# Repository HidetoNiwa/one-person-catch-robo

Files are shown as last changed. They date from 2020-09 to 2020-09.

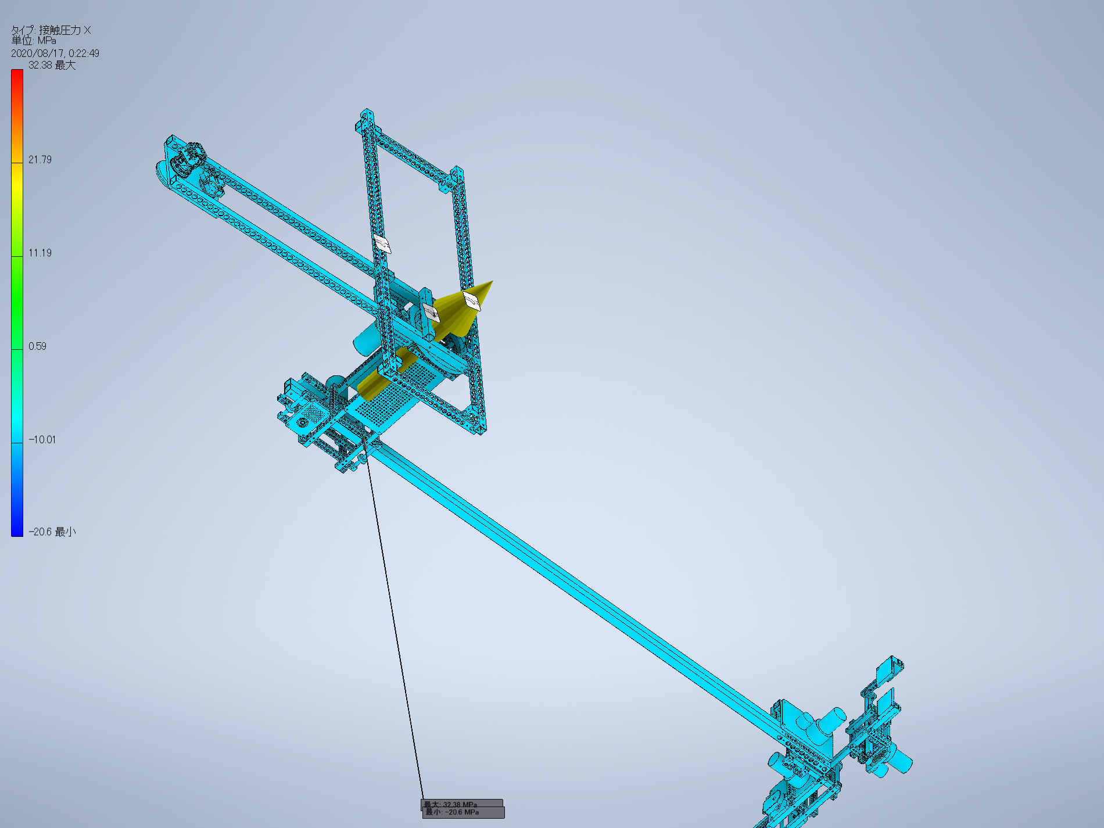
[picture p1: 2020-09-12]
CAD/ロボット/Images/ロボット.iam 構造解析レポート 2020_07_17/0/Result_0_77_rev.png

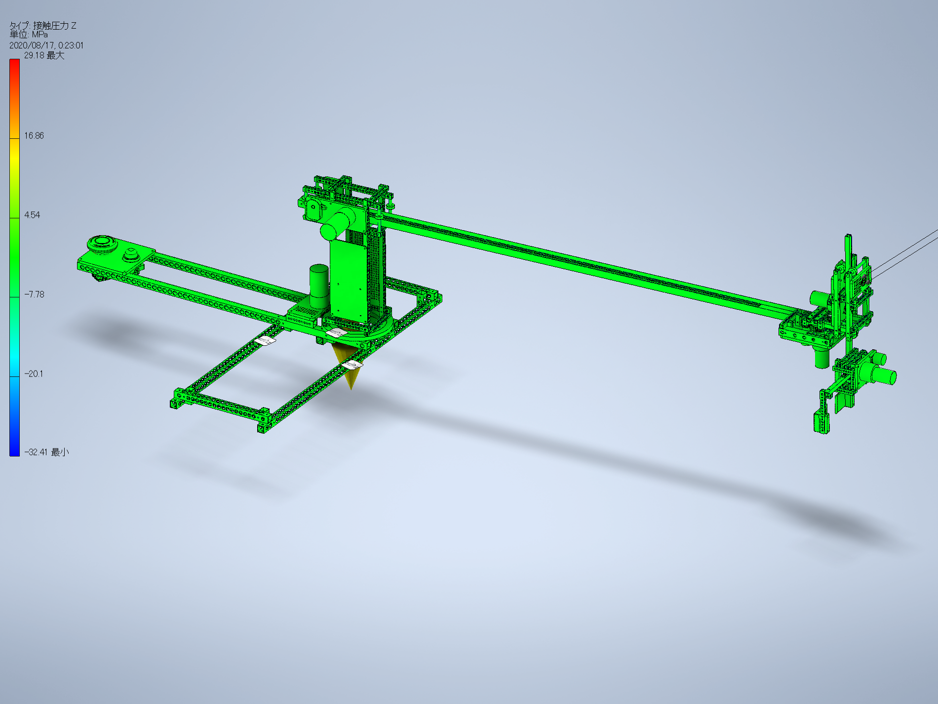
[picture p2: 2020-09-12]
CAD/ロボット/Images/ロボット.iam 構造解析レポート 2020_07_17/0/Result_0_79.png

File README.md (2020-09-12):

# one-person-catch-robo

[#１人キャチロボ]() のリポジトリ

## CAD

* 全体.iam：ロボット全体設計（フィールド込み）
* ロボット.iam：ロボット設計

そのほか、構造解析レポートとかもあります。

### 開発ソフトウェア

Autodesk Inventor Professional 2020

学生版ライセンスで使用可能

## KiCAD

* メインボード.pro：メインボードの設計

### 開発ソフトウェア

KiCAD 5.1.3

## 公式提出資料

## YOLO環境構築

### 環境

Jetson Nano

### 方法

https://www.nakasha.co.jp/future/ai/vol2_yolov3nvidia_jetson_nano.html

OpenCVのver.4系だとうまくコンパイル-できなかった

https://pickerlab.net/2018/08/06/darknet-eroor-nvcc/

### 学習用ファイルラベリング「labelimg」

参考；https://symfoware.blog.fc2.com/blog-entry-2420.html

PyQTのバージョン：5.14.1
デフォルトのインストール設定では、5.10.1になっているのを書き換える（pip配布の問題）

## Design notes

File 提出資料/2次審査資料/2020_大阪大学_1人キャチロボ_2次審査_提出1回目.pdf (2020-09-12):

# 1人キャチロボ ～阪大の老害～

大阪大学大学院 基礎工学研究科
機能創成専攻 博士前期課程1年
丹羽 英人

## 自己紹介/チーム名紹介

キャチロボバトルコンテスト参加歴
2016：Team豊中 － 選手（回路製作）
2017：阪大の老害－選手（回路製作）
2018：運営
2019：運営（学生MC）
2020：阪大の老害 ～1人キャチロボ～ － 選手（全体設計）

2年ぶり3回目の選手としての参加
（キャチロボ10年のうち5年も関わってたんだね）

## 本日の構成

1. 戦略
2. 機構紹介
3. 回路設計
4. 大会までの2週間何をするか

## コンセプト/戦略

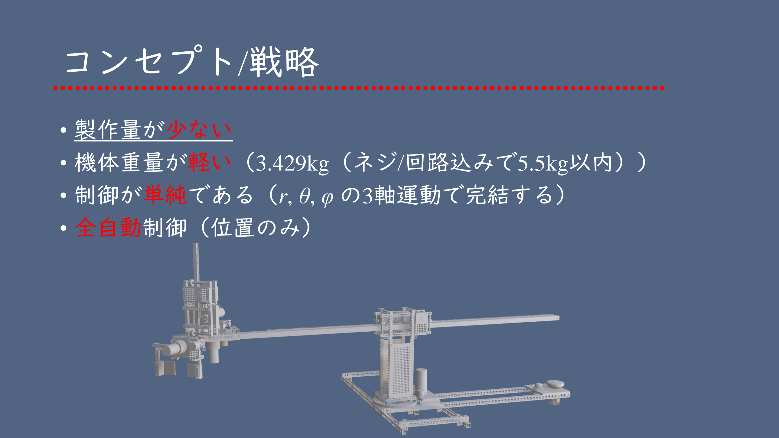
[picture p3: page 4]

- 製作量が少ない
- 機体重量が軽い（3.429kg（ネジ/回路込みで5.5kg以内））
- 制御が単純である（r, θ, φ の3軸運動で完結する）
- 全自動制御（位置のみ）

## 機体全景

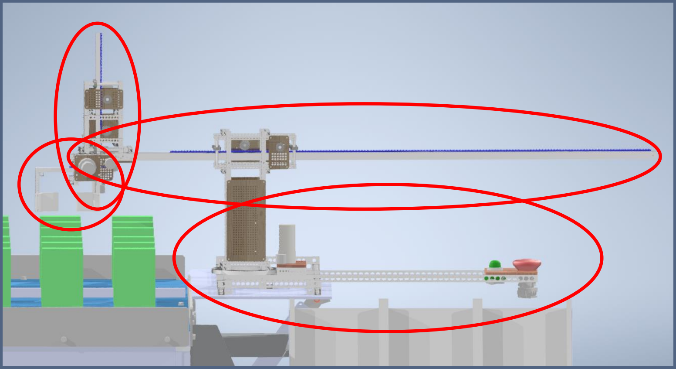
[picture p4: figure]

1. 前後直動アーム
2. 上下直動/
ハンド回転
3. ロボットベース/
アーム回転
4. ハンド部

## 機構紹介（前後直動アーム）

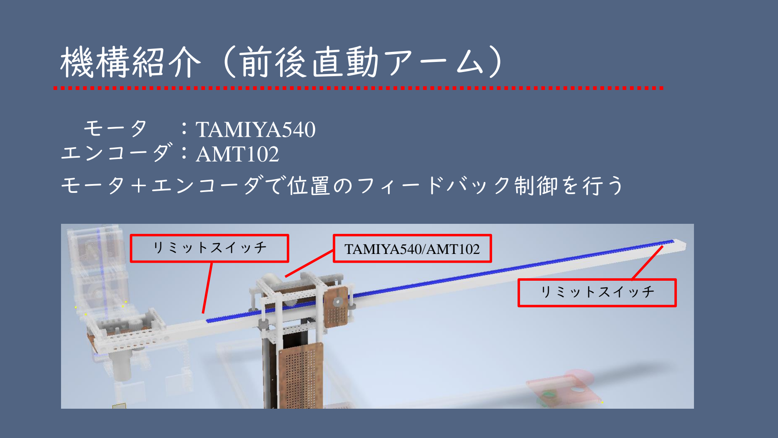
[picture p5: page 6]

モータ ：TAMIYA540
エンコーダ：AMT102
モータ＋エンコーダで位置のフィードバック制御を行う

TAMIYA540/AMT102

リミットスイッチ

リミットスイッチ

## 機構紹介（上下直動アーム/ハンド回転）

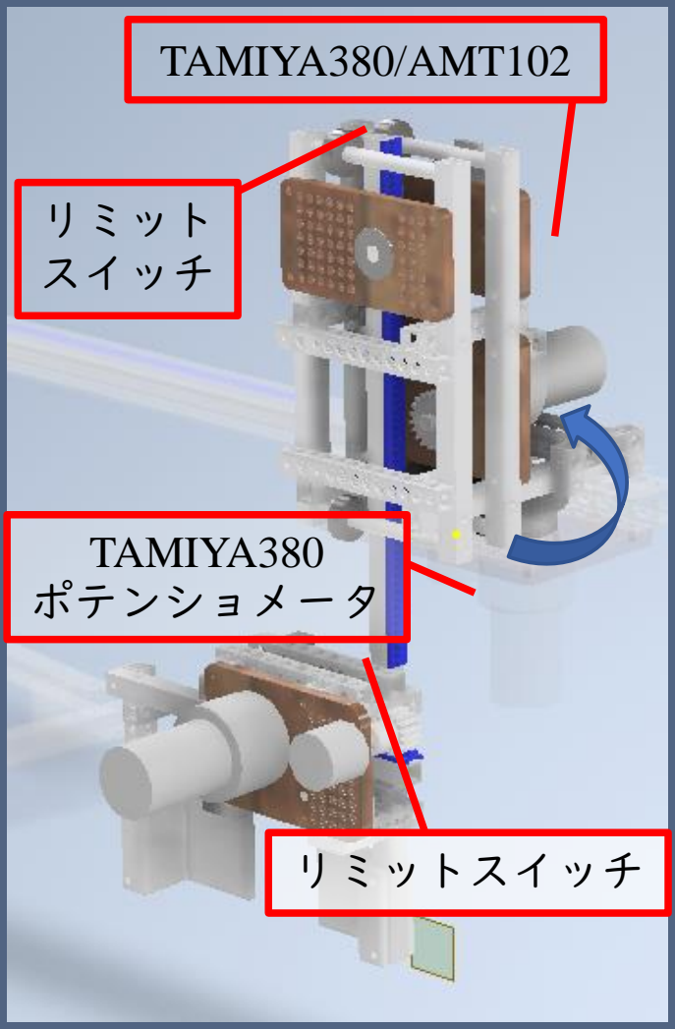
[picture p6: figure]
リミット スイッチ; リミットスイッチ; TAMIYA380/AMT102; TAMIYA380 ポテンショメータ

【上下直動アーム】
モータ ：TAMIYA380
エンコーダ：AMT102
モータ＋エンコーダで位置フィードバック
制御を行う
【ハンド回転】
モータ ：TAMIYA380
モータ＋ポテンショメータで位置制御

## 機構紹介（ハンド回転）

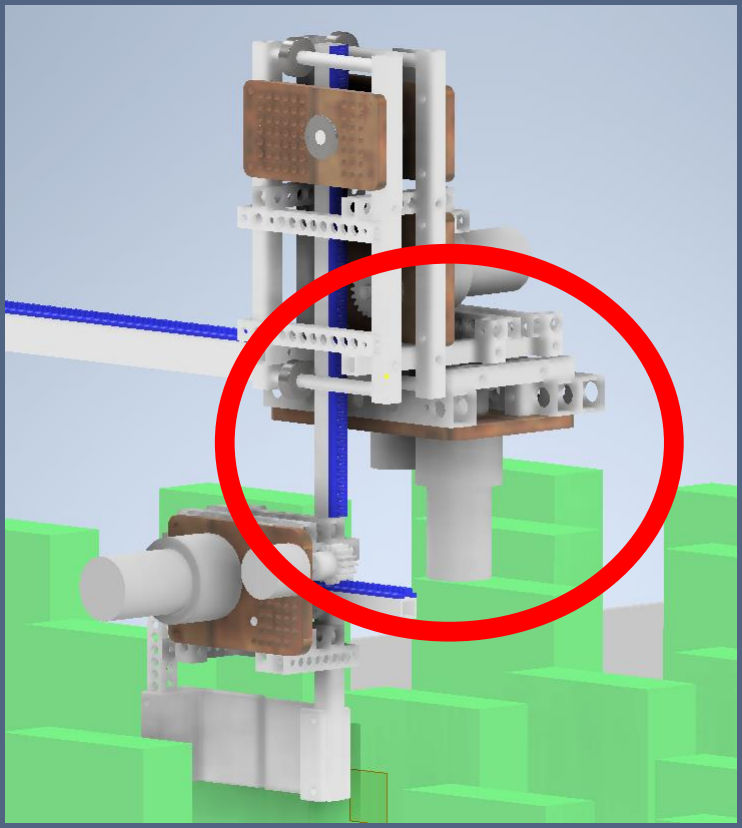
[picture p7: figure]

ハンド回転機構によって、
ワークを把持して向きを
調整することが出来る

ボーナス条件B達成可能

## 機構紹介（ロボットベース/アーム回転）

モータ：TAMIYA540

モータ＋ポテンショメータで位置フィードバック制御

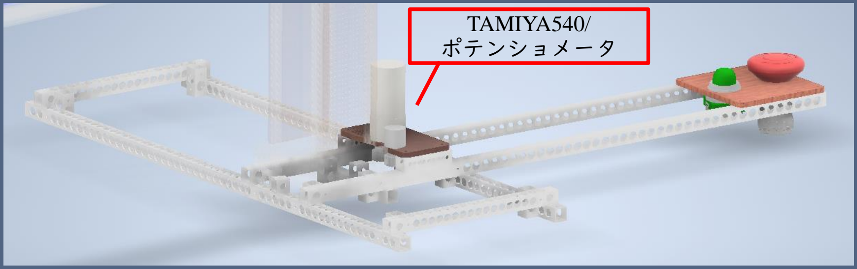
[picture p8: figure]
TAMIYA540/ ポテンショメータ

## 機構紹介（ハンド）

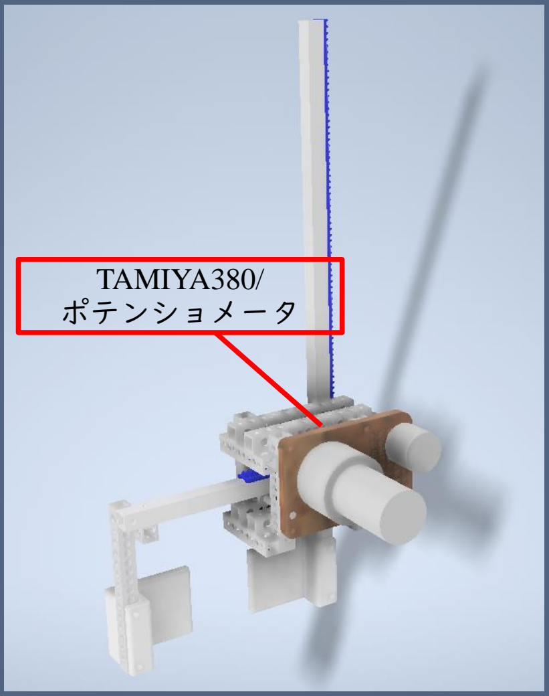
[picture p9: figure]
TAMIYA380/ ポテンショメータ

モータ ：TAMIYA380
モータ＋ポテンショメータで位置制御

ハンド先端は3Dプリンタで造形
ポテンショメータで開閉具合を検出可能

## 機構紹介（強度解析）

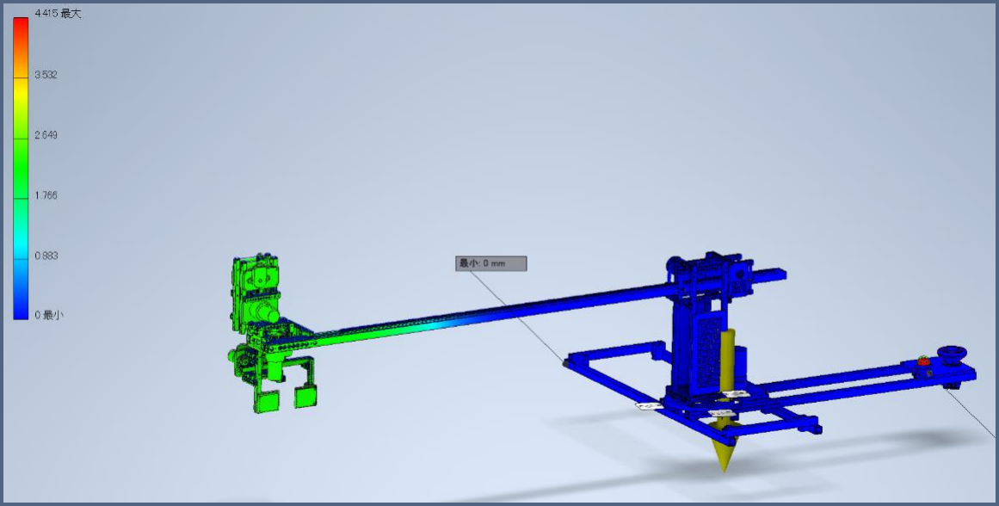
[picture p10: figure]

よし！！！

## 機構紹介（まとめ）

使用するモータ/エンコーダの種類を統一することで
製作コストを下げる

モータ
TAMIYA540：トルク重視な場所
TAMIYA380：速度/質量軽量化したい場所（アームの先端など）

ポテンショメータ：回転量が少ない部分（絶対位置が分かる） エンコーダ（AMT-102）：回転量が多い直動部分

## ワーク取得アルゴリズム

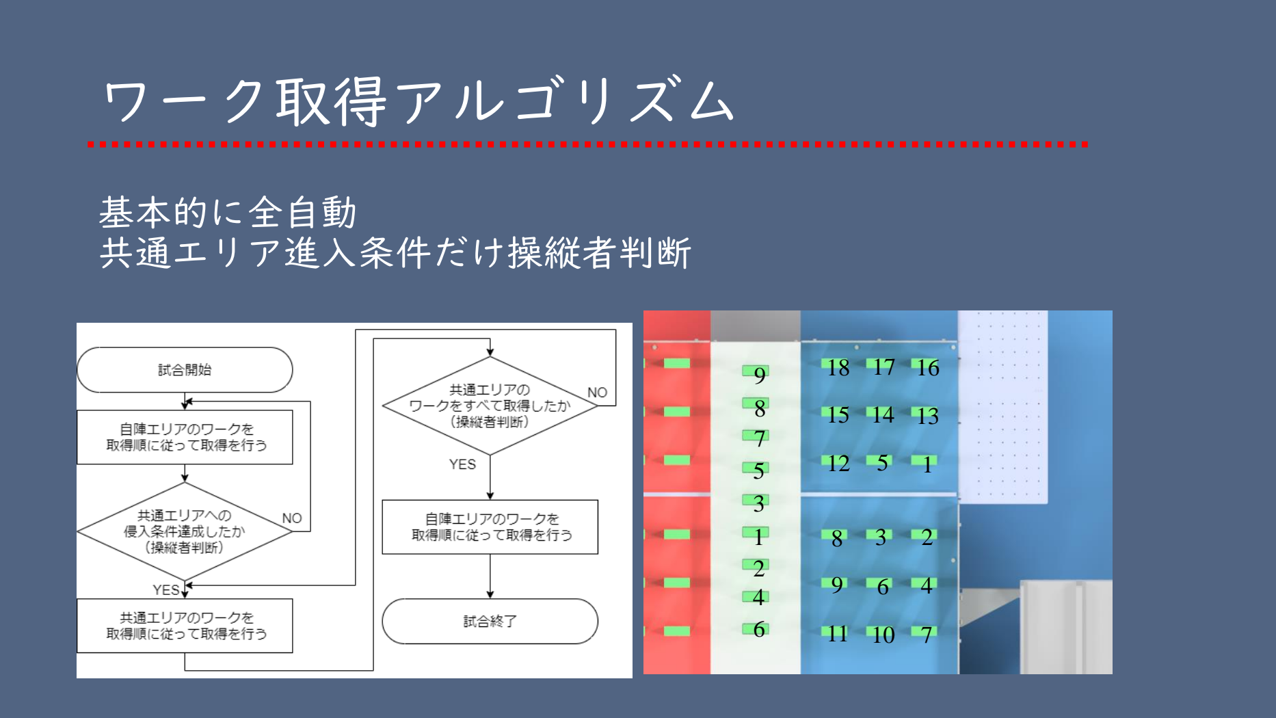
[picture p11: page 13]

基本的に全自動
共通エリア進入条件だけ操縦者判断

1

3 | 2
| 4

5

6

7

8

9

11 10

12

15 14 13

18 17 16

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
## 機構動作順

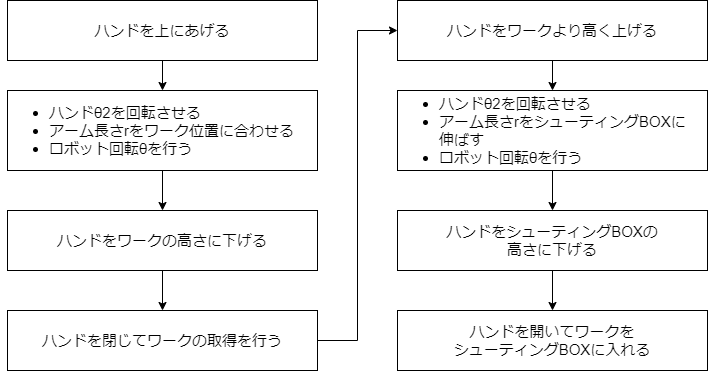
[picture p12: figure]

7秒で1個 / 3分間で25個獲得可能

## 赤/青コート対称性に関して

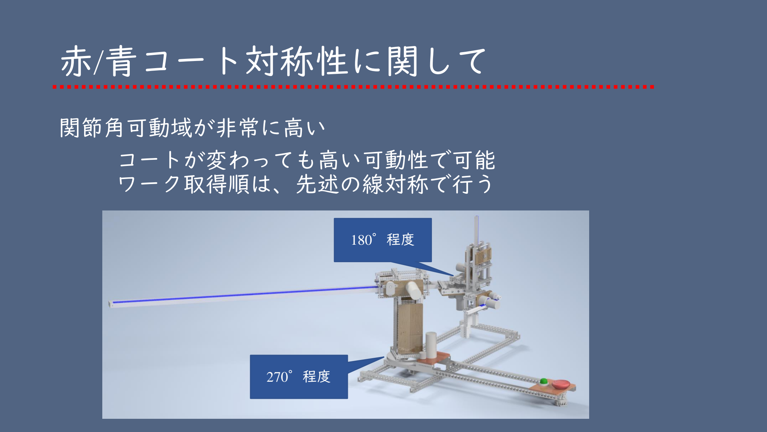
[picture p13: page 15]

関節角可動域が非常に高い
コートが変わっても高い可動性で可能
ワーク取得順は、先述の線対称で行う

270°程度

180°程度

## 拡張性

重量制限まで約10kg程度 余裕あり

単純にアーム数を2倍にすることも可能
→干渉を考量した制御を行う必要がある

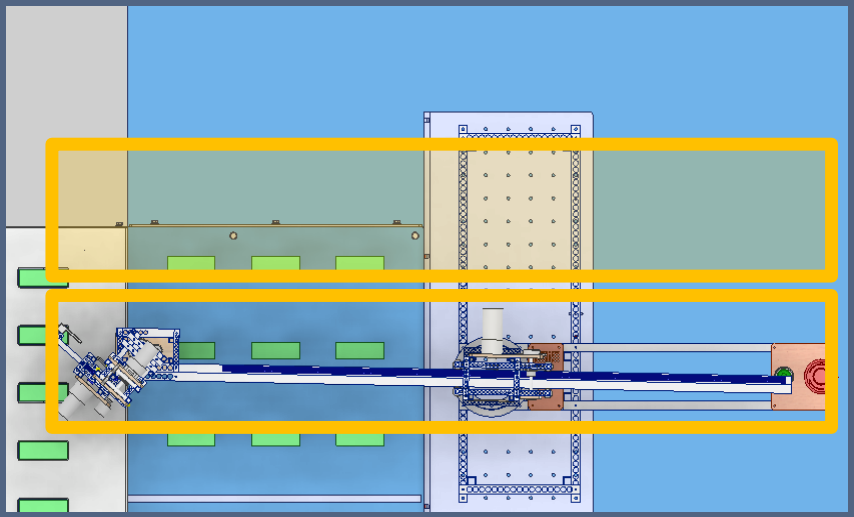
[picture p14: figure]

## 回路設計

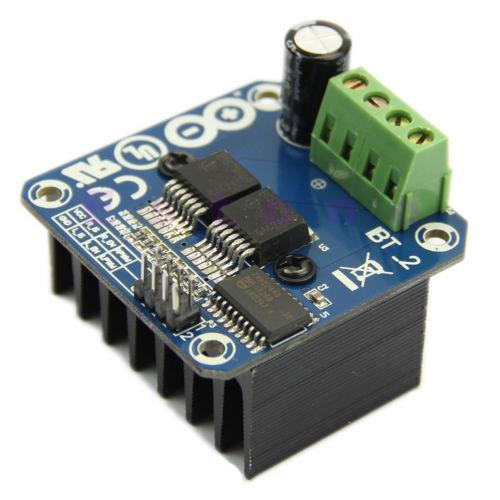
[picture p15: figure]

モータ+ポテンショメータ：3か所
モータ＋エンコーダ+リミットスイッチ：2か所

コントローラ：PS4 dualshock4
（受信部）ATmega328P-AU＋USBホストシールド 受信部<-（CAN通信）->メインマイコン

## 回路設計

【出力】
- PWM出力（(A,B)2相）x5
- LED x4 （Debug出力用）

【入力】
- リミットスイッチ入力x2
- アナログ入力（ポテンショメータ用）x3
- エンコーダ入力（ (A,B)2相）x3

## 回路設計

【通信】
- CAN通信x1
（メインマイコン<->コントローラ受信部<->（拡張用ポート））
- Serial通信x1（メインマイコン<-->USB-Serial変換器）

【電源】
- +12V→+5V→+3.3V変換

これらの仕様に合うようにKiCADで設計
STM32F446REをメインマイコンに設計

## 回路設計

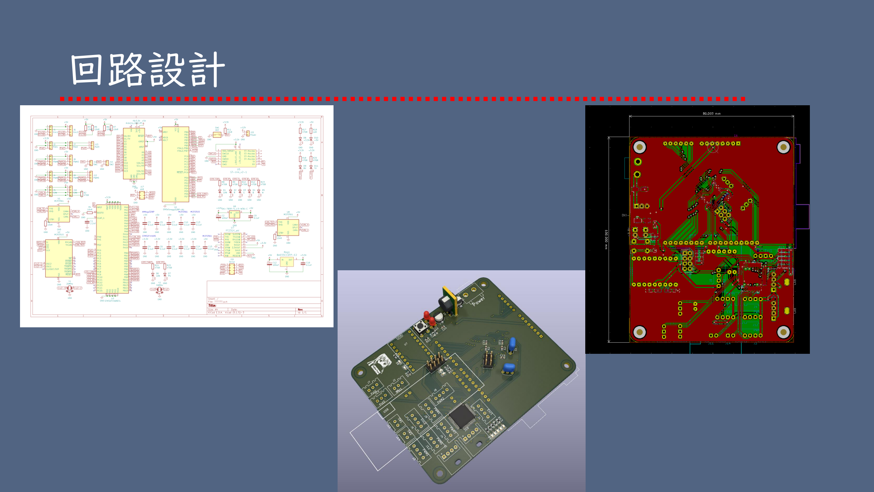
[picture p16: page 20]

## 大会まで2週間に

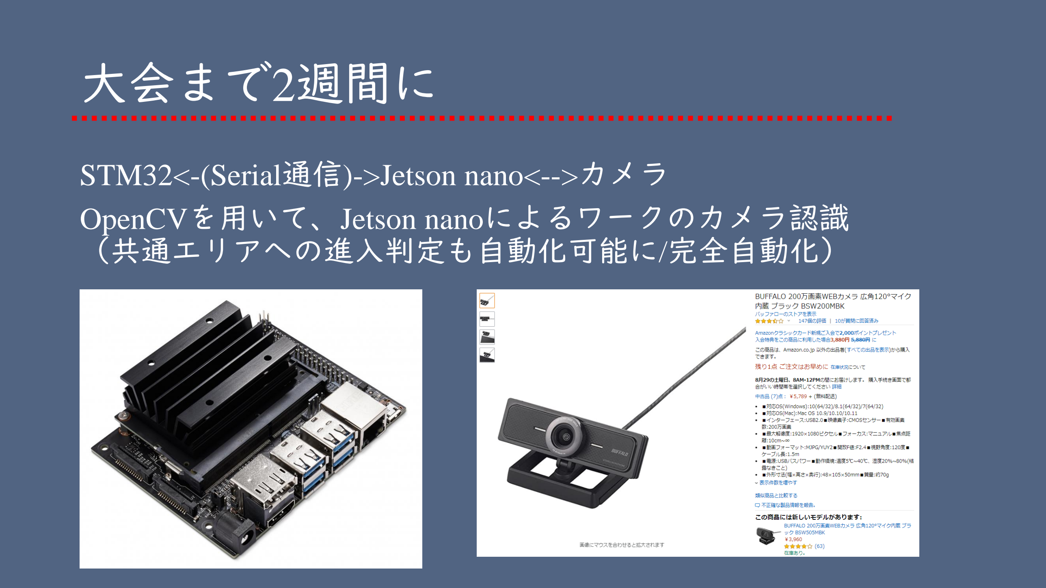
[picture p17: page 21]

STM32<-(Serial通信)->Jetson nano<-->カメラ OpenCVを用いて、Jetson nanoによるワークのカメラ認識 （共通エリアへの進入判定も自動化可能に/完全自動化）

## 最後に

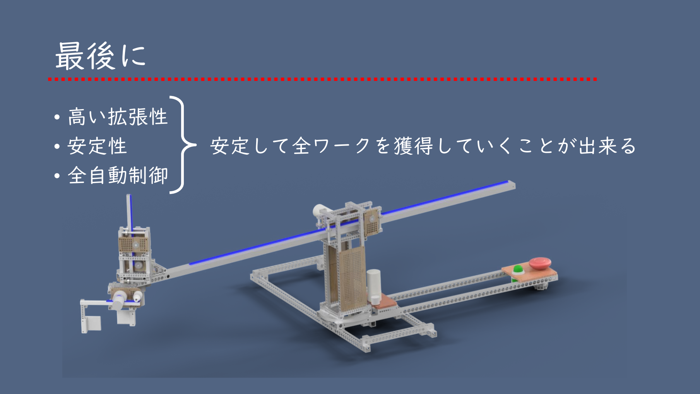
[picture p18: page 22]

- 高い拡張性
- 安定性 | 安定して全ワークを獲得していくことが出来る
- 全自動制御

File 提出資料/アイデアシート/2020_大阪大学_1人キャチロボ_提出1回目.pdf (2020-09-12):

## 提出締切り：2020/8/3 提出先：キャチロボ事務局

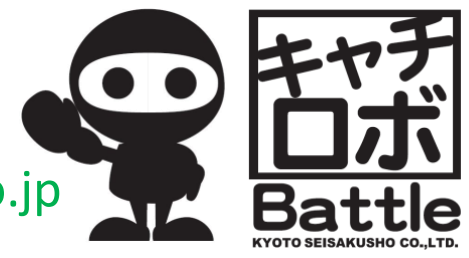
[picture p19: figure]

## E-mail : catchrobo@kyotoss.co.jp

# 大阪大学

## Team 「1人キャチロボ ～阪大の老害～」

# 第10回キャチロボバトルコンテスト アイデアシート

## -Member-丹羽 英人

## 1.コンセプト・戦略

2

Check Point
✓ ルールブックの違反項目に抵触する戦略を立てていませんか？

・製作量が少ない
・機体重量が軽い（3.649kg（ネジ/回路込みで 5.5kg）） ・簡単な制御性

をコンセプトに安定して動作する設計にしている。
アームは1つとして動作干渉が起きないようにしている。

制御としてr,Θ,zの3軸を基準としている
すべてのモータにエンコーダ/ポテンショメータをセットし全自 動にて安定した動作をさせる

## 2.ロボットの構成

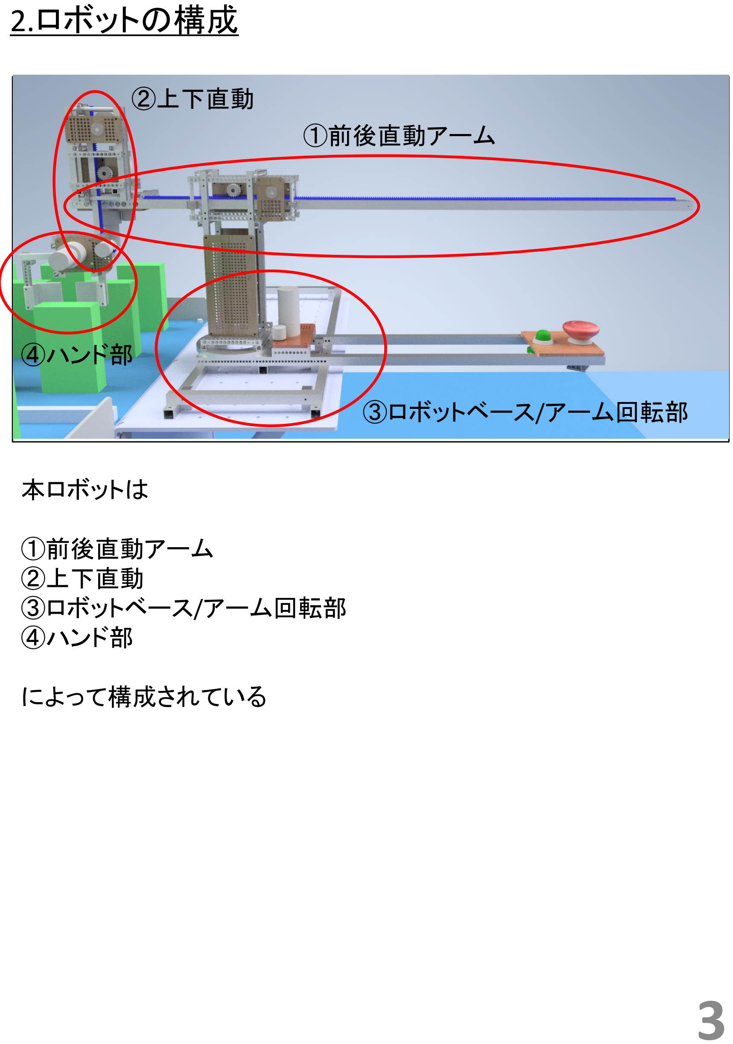
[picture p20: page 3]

3

①前後直動アーム

②上下直動

③ロボットベース/アーム回転部

④ハンド部

本ロボットは

①前後直動アーム
②上下直動
③ロボットベース/アーム回転部
④ハンド部

によって構成されている

## 3.ロボットユニット詳細

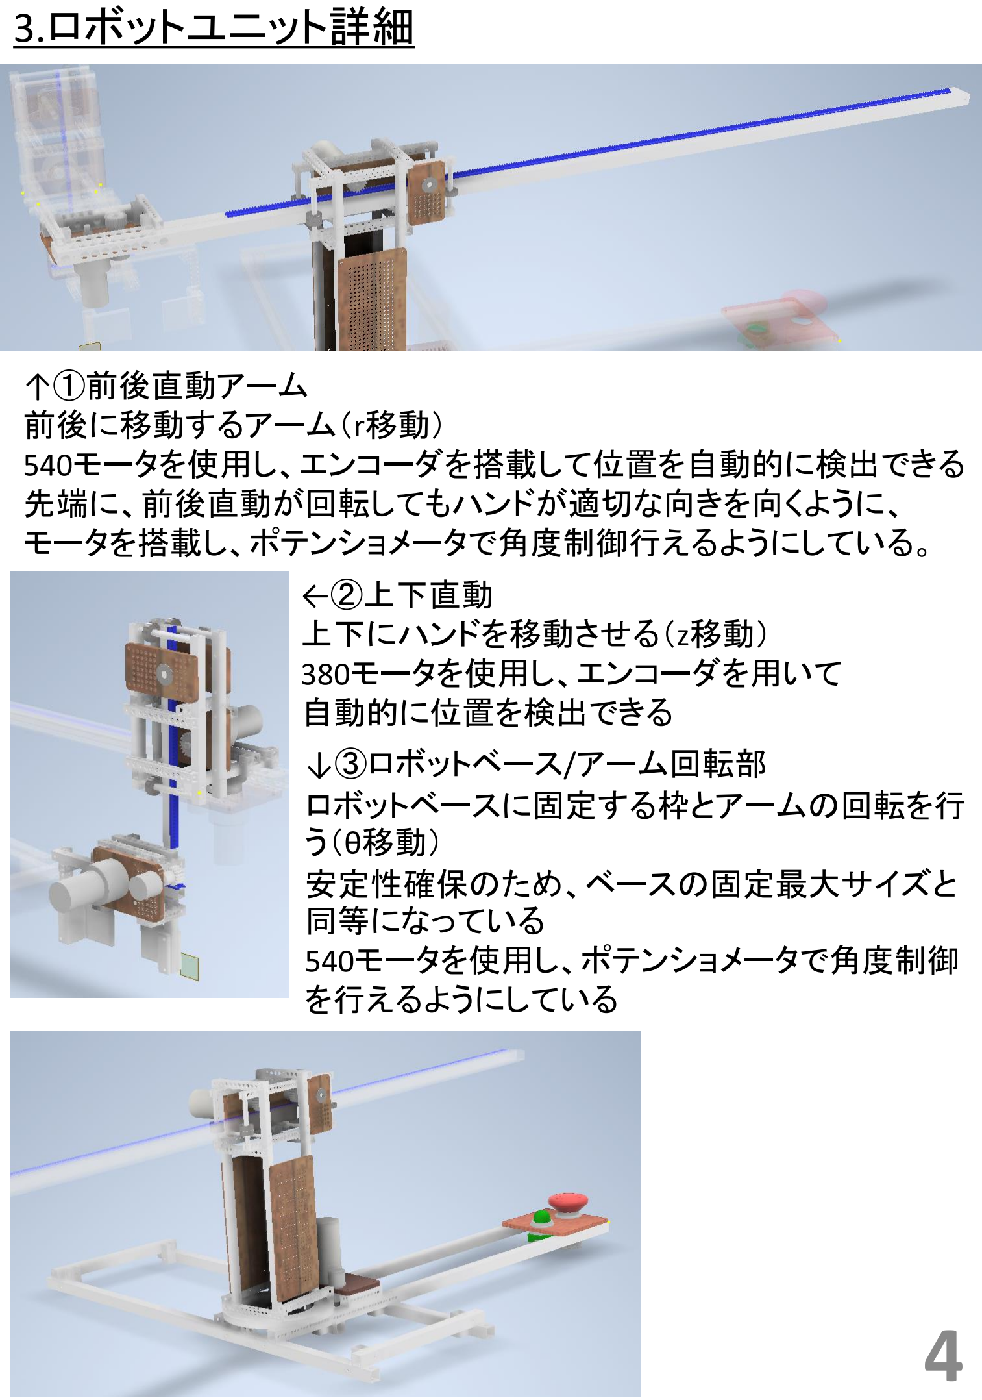
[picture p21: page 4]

4

↑①前後直動アーム
前後に移動するアーム（r移動）
540モータを使用し、エンコーダを搭載して位置を自動的に検出できる 先端に、前後直動が回転してもハンドが適切な向きを向くように、 モータを搭載し、ポテンショメータで角度制御行えるようにしている。 ←②上下直動
上下にハンドを移動させる（z移動）
380モータを使用し、エンコーダを用いて
自動的に位置を検出できる
↓③ロボットベース/アーム回転部
ロボットベースに固定する枠とアームの回転を行
う（θ移動）
安定性確保のため、ベースの固定最大サイズと
同等になっている
540モータを使用し、ポテンショメータで角度制御
を行えるようにしている

## 3.ロボットユニット詳細

5

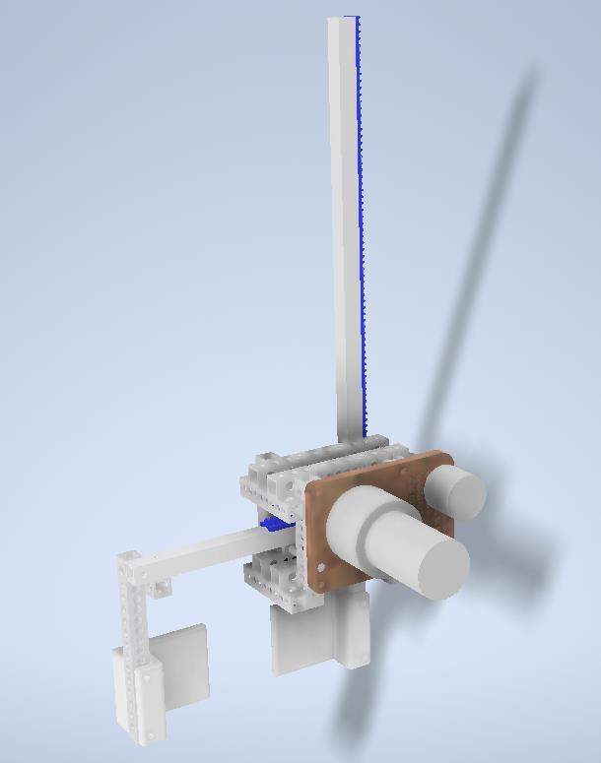
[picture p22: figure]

↑④ハンド部
ワークを挟んで掴む機構、1個ずつワークを確実に掴む
ハンドの先端は3Dプリンタでできている
380モータを使用し、ポテンショメータで開閉具合を検出できる

## 4.ロボット主要寸法（スタート時）

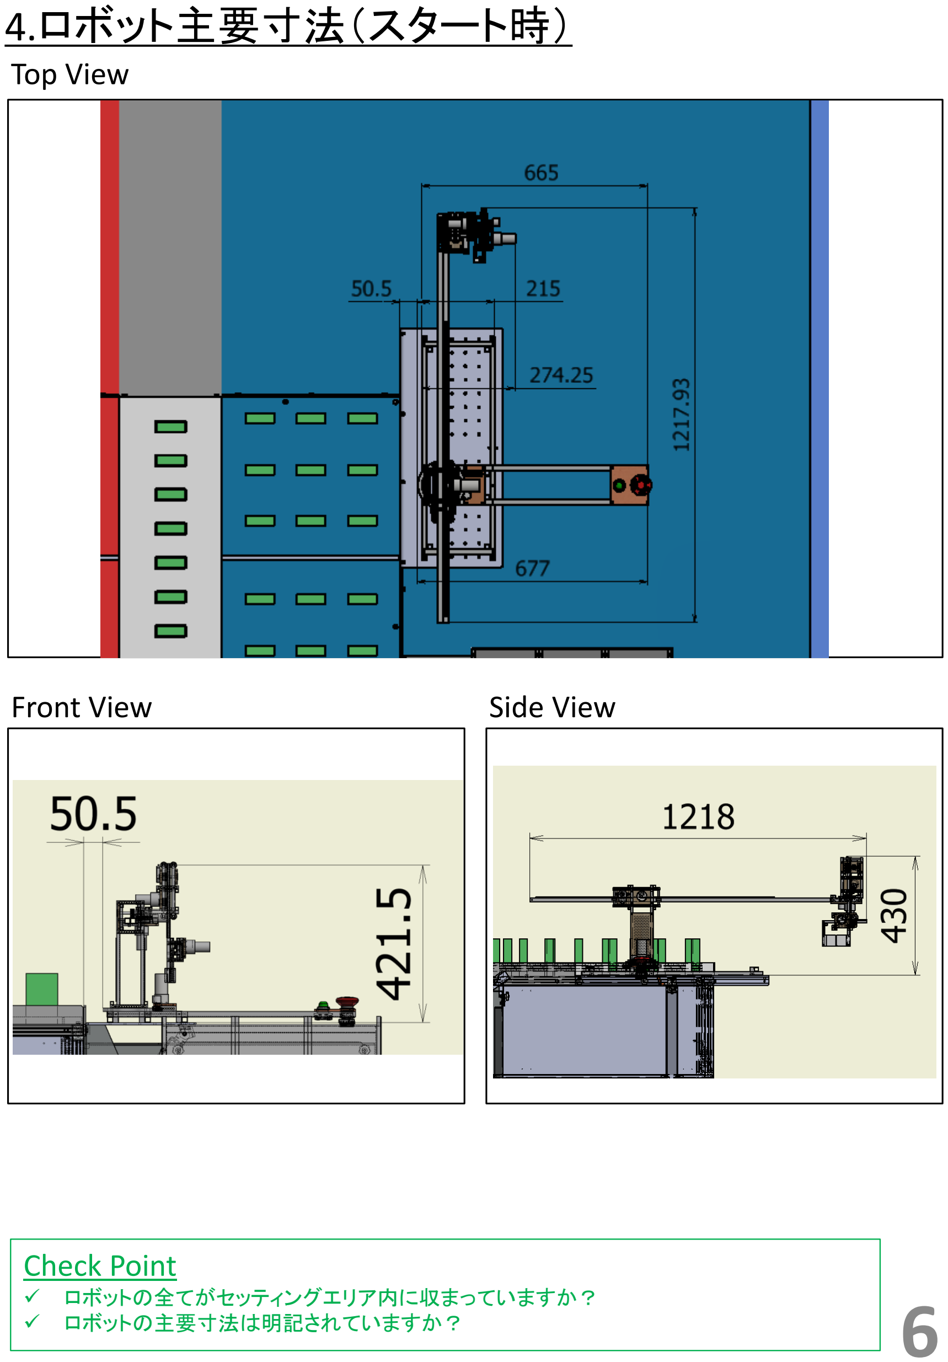
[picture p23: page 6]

✓ | ロボットの全てがセッティングエリア内に収まっていますか？
✓ | ロボットの主要寸法は明記されていますか？

Top View

Front View | Side View

6

## 4.ロボット主要寸法（可動範囲）

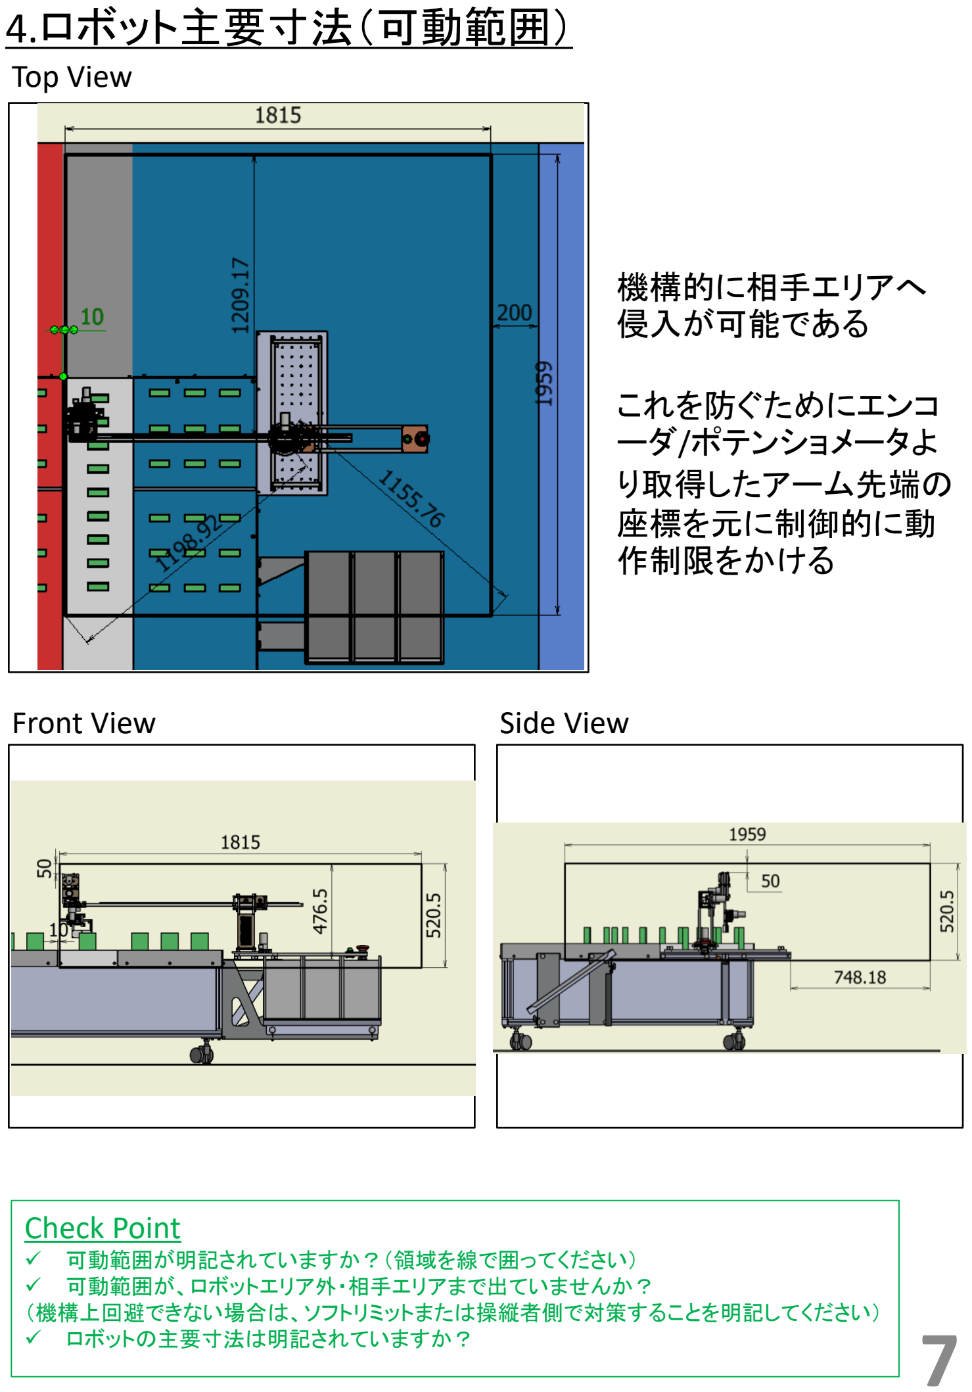
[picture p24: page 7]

Check Point
✓ | 可動範囲が明記されていますか？（領域を線で囲ってください）
✓ | 可動範囲が、ロボットエリア外・相手エリアまで出ていませんか？
（機構上回避できない場合は、ソフトリミットまたは操縦者側で対策することを明記してください） ✓ ロボットの主要寸法は明記されていますか？

Top View

Front View | Side View

7

機構的に相手エリアへ
侵入が可能である

これを防ぐためにエンコ
ーダ/ポテンショメータよ
り取得したアーム先端の
座標を元に制御的に動
作制限をかける

## 5.ワークのハンドリング方法（ワークエリア内）

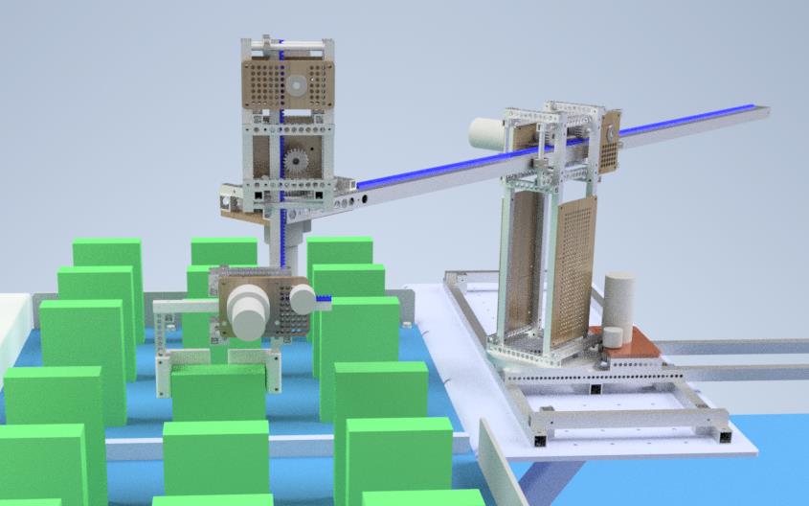
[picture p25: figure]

✓ | 突刺す、接着するなど、ワークを破損させる方法でハンドリングしていませんか？ | 8

以下の数字はP.3に記載のロボットの構成に共通する

③回転運動 部分を回転させる（ポテンショメータで自動化） →①前後直動アーム でワーク上に移動する（エンコーダで自動化） →②上下直動部分と ①前後直動アーム の結合部を回転させ、箱を 把持できる向きにする
→②上下直動部分を下におろす
→④ハンド部 でワークを挟み込んでハンドリングを行う。

## 5.ワークのハンドリング方法（共通エリア内）

✓ | 突刺す、接着するなど、ワークを破損させる方法でハンドリングしていませんか？ | 9

ワークエリア内と同様

## 6.得点に関する条件の達成方法（得点条件）

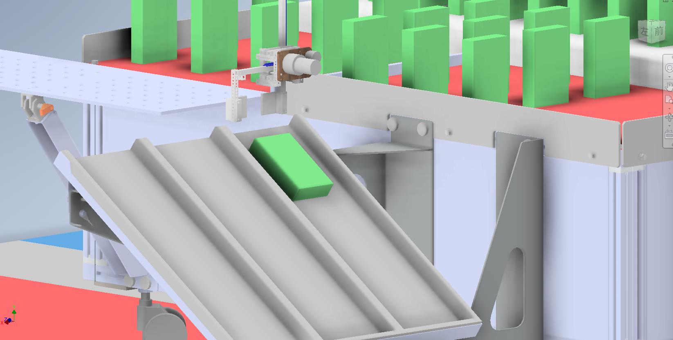
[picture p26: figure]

10

ハンドリング機構でワークを挟んで把持し、ロボットアーム でシューティングBOX上に向かい、シューティングBOX手前 から落とし、シューターに滑らせてワークを入れる。

## 6.得点に関する条件の達成方法（ボーナス条件A）

11

1つ1つハンドリングを行い全自動で確実に入れる。

## 6.得点に関する条件の達成方法（ボーナス条件B）

12


赤丸部に設置されたハンド回転機構によって180度
回転可能になっているため、達成できる

## 7.非常停止ボタンと動力電源表示灯


Check Point
✓ | プッシュロックリターンリセット式の非常停止ボタンを使用していますか？
✓ | 非常停止ボタンは、操縦エリアから押せる位置にありますか？位置を明記していますか？
| （操縦エリアから500mmの範囲内への設置を推奨します）
✓ | 可動部に非常停止ボタンを設置してませんか？（固定部に設置してください）
✓ | 動力電源表示灯は審判が確認できる位置にありますか？
✓ | 動力電源表示灯は緑色に点灯しますか？（それ以外に緑色ランプを使用していませんか？）

Top View

13

動力源表示灯
（APN111DNG）

非常停止スイッチ
（XN1E-BV504MRH）

## 8.フィールドへのロボット固定方法


✓ | ロボットはロボットベースに固定していますか？（地面に接地してないですか？）
✓ | 固定はボルト・ナットなどでしっかり固定できていますか？ | 14

赤矢印部分にてM5の蝶ネジにて固定

## 9.アピール項目１（タイミングチャート）

ワーク回収; 7 sで 1個 3分間で25個
計50ポイント

✓ | すべての軸を書けていますか？
✓ | 1回のワークを取る動作を書けていますか？ | 15

3分間

## 9.アピール項目１（タイミングチャート）


✓ | すべての軸を書けていますか？
✓ | 1回のワークを取る動作を書けていますか？ | 16

1回の動作

Θ
ロボット回転 A地点

B地点 移動距離：
90度
0 | 1 | 2 | 3 | 4 | 5 | 6 | 7

A地点：シューティングBOX上
B地点：ワークエリア、共通エリアのワーク

r
前後動作 A地点

移動距離：
1000mm

Θ2
ハンド回転

移動距離：
90度

Z
ハンド上下 上

移動距離：
150 mm

ハンド開閉 開

移動距離：
50 mm

下

閉

B地点

90度

0度

## 9.アピール項目２（エア系統図）

✓ | エアアクチュエータを動作さるためのエア系統図が描けていますか？ | 17

エア系統 使用せず

## 9.アピール項目３（アームなどの強度計算）


✓ 目標となるたわみを設定し、安全率の評価が出来ていますか？
18

安全率最小値：5
変異がアーム先端で2mm程度となっているので問題ない

## 9.アピール項目４（モータトルク、エアシリンダ推力）

✓ | 目的の動作に対しモータのトルク、回転数、シリンダの推力は余裕代がありますか？ | 19
使用用途 | ハンド開閉
モータ型式 | 380
定格トルク[Nm] | 0.011
最大回転数[rpm] | 30250
減速比 | 10:1
出軸負荷トルク[Nm] | 0.0068
所望回転数[rpm] | 150

モータ①

使用用途 | ハンド上下
モータ型式 | 380
定格トルク[Nm] | 0.011
最大回転数[rpm] | 30250
減速比 | 10:1
出軸負荷トルク[Nm] | 0.0735
所望回転数[rpm] | 180

モータ②

## 9.アピール項目４（モータトルク、エアシリンダ推力）

✓ | 目的の動作に対しモータのトルク、回転数、シリンダの推力は余裕代がありますか？ | 20
使用用途 | ハンド回転
モータ型式 | 380
定格トルク[Nm] | 0.011
最大回転数[rpm] | 30250
減速比 | 36:1
出軸負荷トルク[Nm] | 0.5670
所望回転数[rpm] | 180

モータ③

使用用途 | 前後直動
モータ型式 | 540
定格トルク[Nm] | 0.026
最大回転数[rpm] | 27625
減速比 | 36:1
出軸負荷トルク[Nm] | 0.3054
所望回転数[rpm] | 350

モータ④

## 9.アピール項目４（モータトルク、エアシリンダ推力）

✓ | 目的の動作に対しモータのトルク、回転数、シリンダの推力は余裕代がありますか？ | 21

モータ⑤

使用用途 | ロボット回転
モータ型式 | 540
定格トルク[Nm] | 0.026
最大回転数[rpm] | 27625
減速比 | 75:1
出軸負荷トルク[Nm] | 9.806
所望回転数[rpm] | 150

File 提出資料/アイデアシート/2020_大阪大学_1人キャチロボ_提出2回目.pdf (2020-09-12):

## 提出締切り：2020/8/3 提出先：キャチロボ事務局


## E-mail : catchrobo@kyotoss.co.jp

# 大阪大学

## Team 「1人キャチロボ ～阪大の老害～」

# 第10回キャチロボバトルコンテスト アイデアシート

## -Member-丹羽 英人

## 1.コンセプト・戦略

2

Check Point
✓ ルールブックの違反項目に抵触する戦略を立てていませんか？

・製作量が少ない
・機体重量が軽い（3.429kg（ネジ/回路込みで 5.5kg）） ・簡単な制御性

をコンセプトに安定して動作する設計にしている。
アームは1つとして動作干渉が起きないようにしている。

制御としてr,Θ,zの3軸を基準としている。
すべてのモータにエンコーダ/ポテンショメータを設置してお り、全自動にて安定した動作をさせる。

共通エリアへの侵入判定は、操縦者によって行う。
それまでは自陣エリア内のワークの取得を続ける。

主にロボットベース部分の設計を見直し、肉抜きを多用す ることによって5％の軽量化を図った。（約200g）

## 1.コンセプト・戦略


3

✓ ルールブックの違反項目に抵触する戦略を立てていませんか？

下記にワーク取得におけるアルゴリズムを示す

1

3 | 2
| 4

5

6

7

8

9

11 10

12

15 | 14 | 13
18 | 17 | 16

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
下記にフィールド上面からの様子を示す
それぞれ振られた番号はワーク取得順

## 2.ロボットの構成


4

①前後直動アーム

②上下直動

③ロボットベース/アーム回転部

④ハンド部

本ロボットは

①前後直動アーム
②上下直動
③ロボットベース/アーム回転部
④ハンド部

によって構成されている

## 3.ロボットユニット詳細


5

↑①前後直動アーム
前後に移動するアーム（r移動）
540モータを使用し、エンコーダを搭載して位置を自動的に検出できる 先端に、前後直動が回転してもハンドが適切な向きを向くように、 モータを搭載し、ポテンショメータで角度制御行えるようにしている。 ←②上下直動
上下にハンドを移動させる（z移動）
380モータを使用し、エンコーダで位置制御を
行える
↓③ロボットベース/アーム回転部
ロボットベースに固定する枠とアームの回転を行
う（θ移動）
安定性確保のため、ベースの固定最大サイズと
同等になっている
540モータを使用し、ポテンショメータで角度制御
を行えるようにしている

## 3.ロボットユニット詳細

6


↑④ハンド部
ワークを挟んで掴む機構、1個ずつワークを確実に掴む
ハンドの先端は3Dプリンタでできている
380モータを使用し、ポテンショメータで開閉具合を検出できる

## 4.ロボット主要寸法（スタート時）


✓ | ロボットの全てがセッティングエリア内に収まっていますか？
✓ | ロボットの主要寸法は明記されていますか？

Top View

Front View | Side View

7

## 4.ロボット主要寸法（可動範囲）


Check Point
✓ | 可動範囲が明記されていますか？（領域を線で囲ってください）
✓ | 可動範囲が、ロボットエリア外・相手エリアまで出ていませんか？
（機構上回避できない場合は、ソフトリミットまたは操縦者側で対策することを明記してください） ✓ ロボットの主要寸法は明記されていますか？

Top View

Front View | Side View

8

機構的に相手エリアへ
侵入が可能である

これを防ぐためにエンコ
ーダ/ポテンショメータよ
り取得したアーム先端の
座標を元に制御的に動
作制限をかける

## 5.ワークのハンドリング方法（ワークエリア内）


✓ | 突刺す、接着するなど、ワークを破損させる方法でハンドリングしていませんか？ | 9

以下の数字はP.3に記載のロボットの構成に共通する

③回転運動 部分を回転させる（ポテンショメータで自動化） →①前後直動アーム でワーク上に移動する（エンコーダで自動化） →②上下直動部分と ①前後直動アーム の結合部を回転させ、箱を 把持できる向きにする
→②上下直動部分を下におろす
→④ハンド部 でワークを挟み込んでハンドリングを行う。

## 5.ワークのハンドリング方法（共通エリア内）

✓ | 突刺す、接着するなど、ワークを破損させる方法でハンドリングしていませんか？ | 10

ワークエリア内と同様

## 6.得点に関する条件の達成方法（得点条件）


11

ハンドリング機構でワークを挟んで把持し、ロボットアーム でシューティングBOX上に向かい、シューティングBOX手前 から落とし、シューターに滑らせてワークを入れる。

## 6.得点に関する条件の達成方法（ボーナス条件A）

12

1つ1つハンドリングを行い全自動で確実に入れる。

## 6.得点に関する条件の達成方法（ボーナス条件B）

13


赤丸部に設置されたハンド回転機構によって180度
回転可能になっているため、達成できる。

## 7.非常停止ボタンと動力電源表示灯


Check Point
✓ | プッシュロックリターンリセット式の非常停止ボタンを使用していますか？
✓ | 非常停止ボタンは、操縦エリアから押せる位置にありますか？位置を明記していますか？
| （操縦エリアから500mmの範囲内への設置を推奨します）
✓ | 可動部に非常停止ボタンを設置してませんか？（固定部に設置してください）
✓ | 動力電源表示灯は審判が確認できる位置にありますか？
✓ | 動力電源表示灯は緑色に点灯しますか？（それ以外に緑色ランプを使用していませんか？）

Top View

14

動力源表示灯
（APN111DNG）

非常停止スイッチ
（XN1E-BV504MRH）

## 8.フィールドへのロボット固定方法


✓ | ロボットはロボットベースに固定していますか？（地面に接地してないですか？）
✓ | 固定はボルト・ナットなどでしっかり固定できていますか？ | 15

赤矢印部分にてM5の蝶ネジにて固定を行う。

蝶ネジを用いることで、ロボット設置時に素早く、確実
に固定を行うことが出来る。

## 9.アピール項目１（タイミングチャート）

ワーク回収; 7 sで 1個 3分間で25個; 計50ポイント

✓ | すべての軸を書けていますか？
✓ | 1回のワークを取る動作を書けていますか？ | 16

## 9.アピール項目１（タイミングチャート）

すべての軸を書けていますか？; 1回のワークを取る動作を書けていますか？; 1回の動作; Θ ロボット回転 A地点; B地点 移動距離： 90度; 前後動作; A地点; 移動距離： 1000mm; Θ2 ハンド回転; 移動距離： 90度; ハンド上下; 移動距離： 150 mm; ハンド開閉; 移動距離： 50 mm; B地点

A地点：シューティングBOX上
B地点：ワークエリア、共通エリアのワーク

## 9.アピール項目１（タイミングチャート）


18

✓ | すべての軸を書けていますか？
✓ | 1回のワークを取る動作を書けていますか？

θ
θ2

下記に1動作におけるフローチャートを示す。

フィールド上から見た図
左図の様に、θ, θ2 を
定める

## 9.アピール項目２（エア系統図）

✓ | エアアクチュエータを動作さるためのエア系統図が描けていますか？ | 19

エア系統 使用せず

## 9.アピール項目３（アームなどの強度計算）


✓ 目標となるたわみを設定し、安全率の評価が出来ていますか？
20

安全率最小値：5
変異がアーム先端で2mm程度となっているので問題ない

## 9.アピール項目４（モータトルク、エアシリンダ推力）

✓ | 目的の動作に対しモータのトルク、回転数、シリンダの推力は余裕代がありますか？ | 21
使用用途 | ハンド開閉
モータ型式 | 380
定格トルク[Nm] | 0.011
最大回転数[rpm] | 30250
減速比 | 10:1
出軸負荷トルク[Nm] | 0.0068
所望回転数[rpm] | 150

モータ①

使用用途 | ハンド上下
モータ型式 | 380
定格トルク[Nm] | 0.011
最大回転数[rpm] | 30250
減速比 | 10:1
出軸負荷トルク[Nm] | 0.0735
所望回転数[rpm] | 180

モータ②

安価で軽量な380モータを採用
トルク、回転数ともに十分

安価で軽量な380モータを採用
トルク、回転数ともに十分

## 9.アピール項目４（モータトルク、エアシリンダ推力）

✓ | 目的の動作に対しモータのトルク、回転数、シリンダの推力は余裕代がありますか？ | 22
使用用途 | ハンド回転
モータ型式 | 380
定格トルク[Nm] | 0.011
最大回転数[rpm] | 30250
減速比 | 36:1
出軸負荷トルク[Nm] | 0.5670
所望回転数[rpm] | 180

モータ③

使用用途 | 前後直動
モータ型式 | 540
定格トルク[Nm] | 0.026
最大回転数[rpm] | 27625
減速比 | 36:1
出軸負荷トルク[Nm] | 0.3054
所望回転数[rpm] | 350

モータ④

安価で軽量な380モータを採用
トルク、回転数ともに十分

安価で出力が十分な540モータを採用
トルク、回転数ともに十分

## 9.アピール項目４（モータトルク、エアシリンダ推力）

✓ | 目的の動作に対しモータのトルク、回転数、シリンダの推力は余裕代がありますか？ | 23

モータ⑤

使用用途 | ロボット回転
モータ型式 | 540
定格トルク[Nm] | 0.026
最大回転数[rpm] | 27625
減速比 | 75:1
出軸負荷トルク[Nm] | 9.806
所望回転数[rpm] | 150

安価で出力が十分な540モータを採用
トルク、回転数ともに十分

## 9.アピール項目5（回路設計）

24

今回、モータ仕様として、
・モータ＋ポテンショメータ：3か所
・モータ＋エンコーダ＋リミットスイッチ（初期位置設定用）：2か所 となっている。これに合わせた入出力環境のメインボードを 設計した。本基板は、PCBとして中国へ発注を行い、部品を はんだ付けしてプログラム作成して動作させる予定である。 メインマイコンとして、STM32F446RET6を用いた。

コントローラはPS4 dualshock4 を用いた。 コントローラ受信部は、ATmega328P-AU＋USBホストシールドにて 作成した。コントローラ受信部とメインマイコンの通信には CAN通信を用いた。

モータドライバはIBT-2（5.5V-27V,43A(ピーク100A)）を採用した。

＜搭載機能＞

CAN通信x1
（メインマイコン<-->コントローラ受信部<-->（外部拡張用ポート）） Serial通信x1（メインマイコン<-->USB-Serial変換器）

PWM出力（(A,B)2相）x5

リミットスイッチ入力x2
アナログ入力（ポテンショメータ用）x3

エンコーダ入力（ (A,B)2相）x3

LED x4 （Debug出力用）

## 9.アピール項目5（回路設計）


25

## 9.アピール項目5（回路設計）


26

基板表面の様子

基板表面の様子
（配線設計済み）

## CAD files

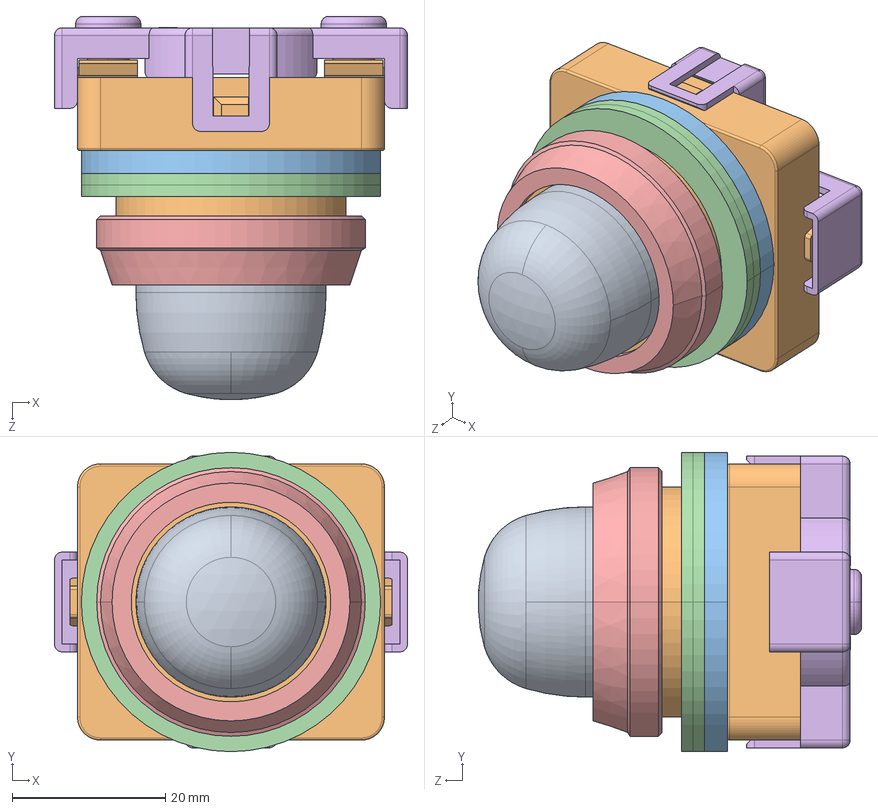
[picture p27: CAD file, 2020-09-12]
CAD/ロボット/共有パーツ/cad_STEP_OUTSIDE-APN1nnDN.STEP
46.0 x 39.0 x 50.0 mm
OUTSIDE-APN本体_ダイレクト用
OUTSIDE-OW-12
OUTSIDE-OW-11 x 2
OUTSIDE-OG-11
OUTSIDE-APN-PVL

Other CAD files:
CAD/全体.dwg
CAD/OldVersions/全体.0003.dwg
CAD/OldVersions/全体.0016.iam
CAD/フィールド/2019Nx-CLB-120U.ipt
CAD/フィールド/2019Nx-×OtbgCLB-120Ux[X.ipt
CAD/フィールド/2020NxJ[ybg(GA}).iam
CAD/フィールド/2020NxJ[ybg.ipt
CAD/フィールド/234_C4_NewSBE(GA}).iam
CAD/フィールド/234_C4_NewSBE.iam
CAD/フィールド/234_C4_NewSB¤ÊÊ.iam
CAD/フィールド/234_C4_NewSB¶(GA}).iam
CAD/フィールド/234_C4_NewSB¶.iam
CAD/フィールド/234_C4_Newt[.iam
CAD/フィールド/234_C4_Newt[_1.iam
CAD/フィールド/234_C4_Newt[AZu(GA}).iam
CAD/フィールド/234_C4_Newt[AZu.iam
CAD/フィールド/234_C4_New{bgx[XAZuE(ZumaEdition).iam
CAD/フィールド/234_C4_New{bgx[XAZu¶(ZumaEdition).iam
CAD/フィールド/234_C4_NewÊÂx¦AZu.iam
CAD/フィールド/234_C4_[Nzñ(GA}).iam
CAD/フィールド/234_ANJo[¤Ê.ipt
CAD/フィールド/234_qW(bN^Cv)_efhl5050hh.iam
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

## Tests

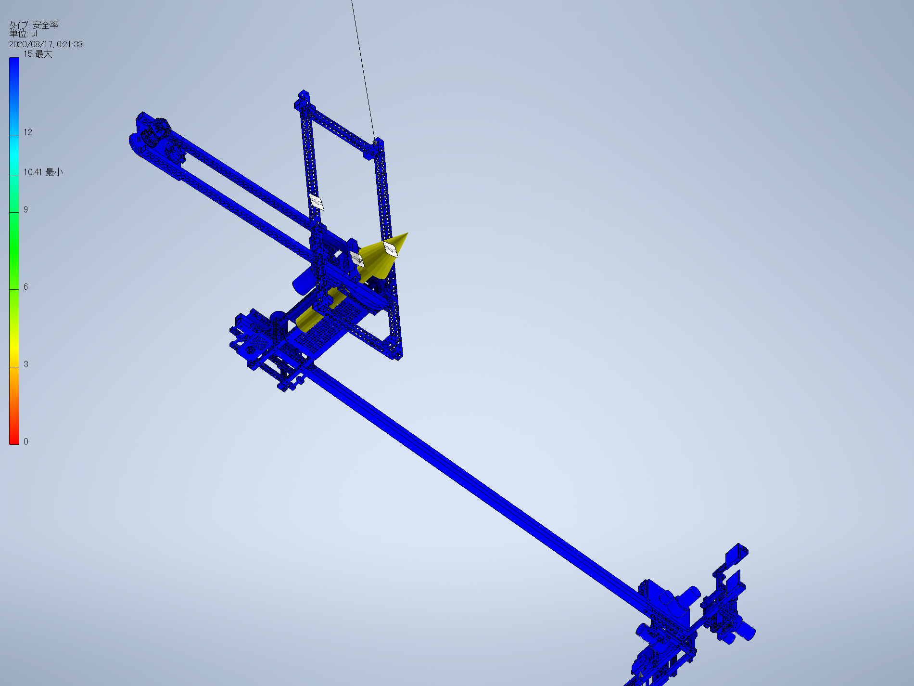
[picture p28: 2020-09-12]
CAD/ロボット/Images/ロボット.iam 構造解析レポート 2020_07_17/0/Result_0_57_rev.png

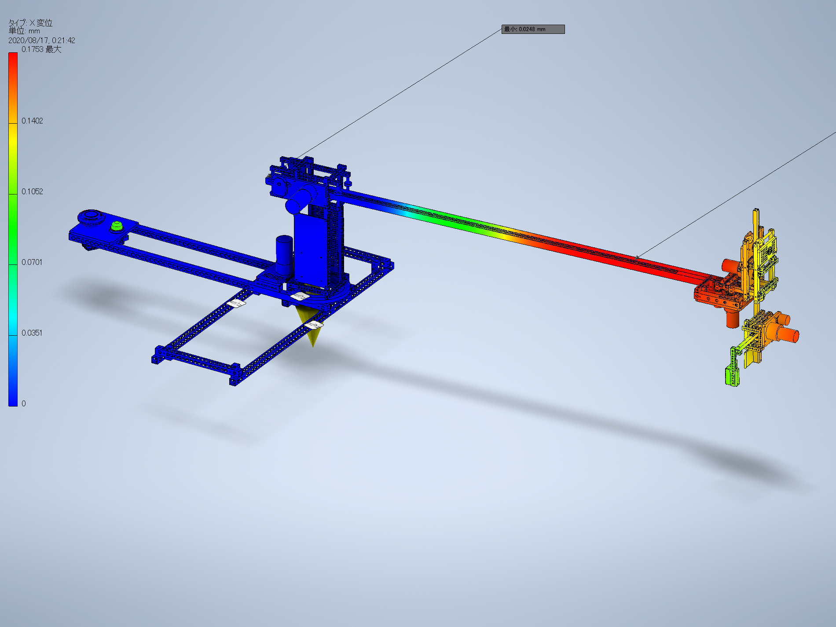
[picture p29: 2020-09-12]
CAD/ロボット/Images/ロボット.iam 構造解析レポート 2020_07_17/0/Result_0_3.png

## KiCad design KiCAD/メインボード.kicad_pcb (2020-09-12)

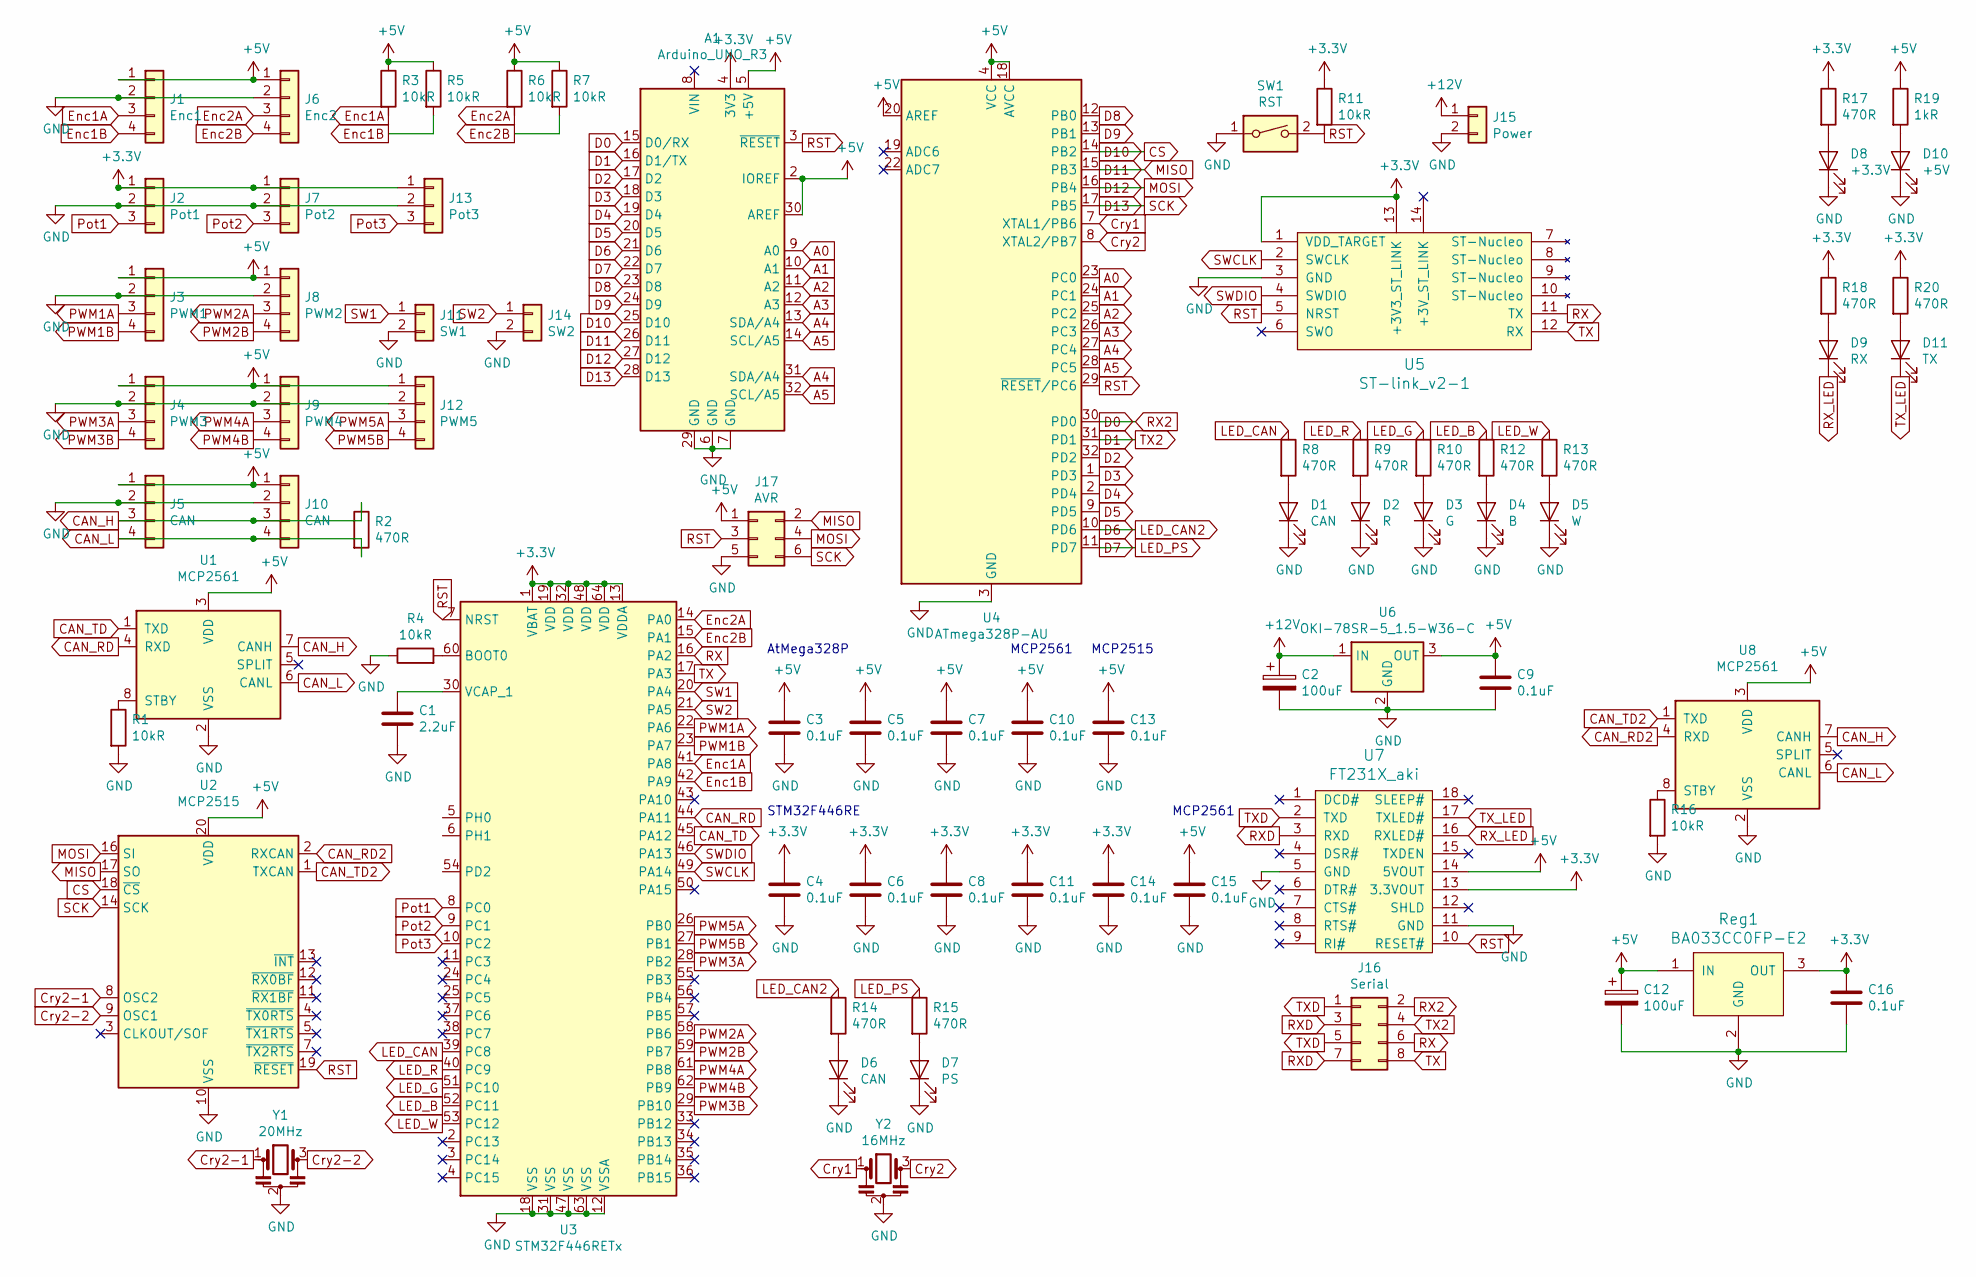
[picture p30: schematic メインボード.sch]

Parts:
A1: Arduino_UNO_R3
C1: 2.2uF; C_0603_1608Metric_Pad1.05x0.95mm_HandSolder
C2, C12: 100uF; CP_Elec_5x3
C3, C4, C5, C6, C7, C8, C9, C10, C11, C13, C14, C15, C16: 0.1uF; C_0603_1608Metric_Pad1.05x0.95mm_HandSolder
D1, D6: CAN; LED_0603_1608Metric_Pad1.05x0.95mm_HandSolder
D2: R; LED_0603_1608Metric_Pad1.05x0.95mm_HandSolder
D3: G; LED_0603_1608Metric_Pad1.05x0.95mm_HandSolder
D4: B; LED_0603_1608Metric_Pad1.05x0.95mm_HandSolder
D5: W; LED_0603_1608Metric_Pad1.05x0.95mm_HandSolder
D7: PS; LED_0603_1608Metric_Pad1.05x0.95mm_HandSolder
D8: +3.3V; LED_D3.0mm
D9: RX; LED_0603_1608Metric_Pad1.05x0.95mm_HandSolder
D10: +5V; LED_D3.0mm
D11: TX; LED_0603_1608Metric_Pad1.05x0.95mm_HandSolder
J1: Enc1; XA_4
J2: Pot1; XA_3
J3: PWM1; XA_4
J4: PWM3; XA_4
J5, J10: CAN; XA_4_Angled
J6: Enc2; XA_4
J7: Pot2; XA_3
J8: PWM2; XA_4
J9: PWM4; XA_4
J11: SW1; XA_2
J12: PWM5; XA_4
J13: Pot3; XA_3
J14: SW2; XA_2
J15: Power; VL_2
J16: Serial; PinHeader_2x04_P2.54mm_Vertical
J17: AVR; PinHeader_2x03_P2.54mm_Vertical
R1, R3, R4, R5, R6, R7, R11, R16: 10kR; R_0603_1608Metric_Pad1.05x0.95mm_HandSolder
R2, R8, R9, R10, R12, R13, R14, R15, R17, R18, R20: 470R; R_0603_1608Metric_Pad1.05x0.95mm_HandSolder
R19: 1kR; R_0603_1608Metric_Pad1.05x0.95mm_HandSolder
Reg1: BA033CC0FP-E2; TO-252-2
SW1: RST; SW_PUSH_6mm
U1, U8: MCP2561; SOIC-8_3.9x4.9mm_P1.27mm
U2: MCP2515; TSSOP-20_4.4x6.5mm_P0.65mm
U3: STM32F446RETx; LQFP-64_10x10mm_P0.5mm
U4: ATmega328P-AU; TQFP-32_7x7mm_P0.8mm
U5: ST-link_v2-1
U6: OKI-78SR-5_1.5-W36-C; Converter_DCDC_muRata_OKI-78SR_Vertical
U7: FT231X_aki
Y1: 20MHz; Resonator-3Pin_W6.0mm_H3.0mm
Y2: 16MHz; Resonator-3Pin_W6.0mm_H3.0mm

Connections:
+3V3: A1.4 (3V3), C4.1, C6.1, C8.1, C11.1, C14.1, C16.1, J2.1, J7.1, J13.1, R11.1, R17.1, R18.1, R20.1, Reg1.3 (OUT), U3.1 (VBAT), U3.13 (VDDA), U3.19 (VDD), U3.32 (VDD), U3.48 (VDD), U3.64 (VDD), U5.1 (VDD_TARGET), U5.13 (+3V3_ST_LINK), U7.13 (3.3VOUT)
+5V: A1.2 (IOREF), A1.5 (+5V), A1.30 (AREF), C3.1, C5.1, C7.1, C9.1, C10.1, C12.1, C13.1, C15.1, J1.1, J3.1, J4.1, J5.1, J6.1, J8.1, J9.1, J10.1, J12.1, J17.1, R3.1, R5.1, R6.1, R7.1, R19.1, Reg1.1 (IN), U1.3 (VDD), U2.20 (VDD), U4.4 (VCC), U4.6 (VCC), U4.18 (AVCC), U4.20 (AREF), U6.3 (OUT), U7.14 (5VOUT), U8.3 (VDD)
+12V: C2.1, J15.1, U6.1 (IN)
A0: A1.9 (A0), U4.23 (PC0)
A1: A1.10 (A1), U4.24 (PC1)
A2: A1.11 (A2), U4.25 (PC2)
A3: A1.12 (A3), U4.26 (PC3)
A4: A1.13 (SDA/A4), A1.31 (SDA/A4), U4.27 (PC4)
A5: A1.14 (SCL/A5), A1.32 (SCL/A5), U4.28 (PC5)
CAN_H: J5.3, J10.3, R2.1, U1.7 (CANH), U8.7 (CANH)
CAN_L: J5.4, J10.4, R2.2, U1.6 (CANL), U8.6 (CANL)
CAN_RD: U1.4 (RXD), U3.44 (PA11)
CAN_RD2: U2.2 (RXCAN), U8.4 (RXD)
CAN_TD: U1.1 (TXD), U3.45 (PA12)
CAN_TD2: U2.1 (TXCAN), U8.1 (TXD)
CS: A1.25 (D10), U2.18 (~CS), U4.14 (PB2)
Cry1: U4.7 (XTAL1/PB6), Y2.1
Cry2: U4.8 (XTAL2/PB7), Y2.3
Cry2-1: U2.8 (OSC2), Y1.1
Cry2-2: U2.9 (OSC1), Y1.3
D0: A1.15 (D0/RX), J16.2, U4.30 (PD0)
D1: A1.16 (D1/TX), J16.4, U4.31 (PD1)
D2: A1.17 (D2), U4.32 (PD2)
D3: A1.18 (D3), U4.1 (PD3)
D4: A1.19 (D4), U4.2 (PD4)
D5: A1.20 (D5), U4.9 (PD5)
D6: A1.21 (D6), R14.1, U4.10 (PD6)
D7: A1.22 (D7), R15.1, U4.11 (PD7)
D8: A1.23 (D8), U4.12 (PB0)
D9: A1.24 (D9), U4.13 (PB1)
D11: A1.26 (D11), J17.2, U2.17 (SO), U4.15 (PB3)
D12: A1.27 (D12), J17.4, U2.16 (SI), U4.16 (PB4)
D13: A1.28 (D13), J17.6, U2.14 (SCK), U4.17 (PB5)
Enc1A: J1.3, R3.2, U3.41 (PA8)
Enc1B: J1.4, R5.2, U3.42 (PA9)
Enc2A: J6.3, R6.2, U3.14 (PA0)
Enc2B: J6.4, R7.2, U3.15 (PA1)
GND: A1.6 (GND), A1.7 (GND), A1.29 (GND), C1.2, C2.2, C3.2, C4.2, C5.2, C6.2, C7.2, C8.2, C9.2, C10.2, C11.2, C12.2, C13.2, C14.2, C15.2, C16.2, D1.1 (K), D2.1 (K), D3.1 (K), D4.1 (K), D5.1 (K), D6.1 (K), D7.1 (K), D8.1 (K), D10.1 (K), J1.2, J2.2, J3.2, J4.2, J5.2, J6.2, J7.2, J8.2, J9.2, J10.2, J11.2, J12.2, J13.2, J14.2, J15.2, J17.5, R1.2, R4.1, R16.2, Reg1.2 (GND), SW1.1, U1.2 (VSS), U2.10 (VSS), U3.12 (VSSA), U3.18 (VSS), U3.31 (VSS), U3.47 (VSS), U3.63 (VSS), U4.3 (GND), U4.5 (GND), U4.21 (GND), U5.3 (GND), U6.2 (GND), U7.5 (GND), U7.11 (GND), U8.2 (VSS), Y1.2, Y2.2
LED_B: R12.1, U3.52 (PC11)
LED_CAN: R8.1, U3.39 (PC8)
LED_G: R10.1, U3.51 (PC10)
LED_R: R9.1, U3.40 (PC9)
LED_W: R13.1, U3.53 (PC12)
unnamed: C1.1, U3.30 (VCAP_1)
unnamed: D1.2 (A), R8.2
unnamed: D2.2 (A), R9.2
unnamed: D3.2 (A), R10.2
unnamed: D4.2 (A), R12.2
unnamed: D5.2 (A), R13.2
unnamed: D6.2 (A), R14.2
unnamed: D7.2 (A), R15.2
unnamed: D8.2 (A), R17.2
unnamed: D9.2 (A), R18.2
unnamed: D10.2 (A), R19.2
unnamed: D11.2 (A), R20.2
unnamed: R1.1, U1.8 (STBY)
unnamed: R4.2, U3.60 (BOOT0)
unnamed: R16.1, U8.8 (STBY)
PWM1A: J3.3, U3.22 (PA6)
PWM1B: J3.4, U3.23 (PA7)
PWM2A: J8.3, U3.58 (PB6)
PWM2B: J8.4, U3.59 (PB7)
PWM3A: J4.3, U3.28 (PB2)
PWM3B: J4.4, U3.29 (PB10)
PWM4A: J9.3, U3.61 (PB8)
PWM4B: J9.4, U3.62 (PB9)
PWM5A: J12.3, U3.26 (PB0)
PWM5B: J12.4, U3.27 (PB1)
Pot1: J2.3, U3.8 (PC0)
Pot2: J7.3, U3.9 (PC1)
Pot3: J13.3, U3.10 (PC2)
RST: A1.3 (~RESET), J17.3, R11.2, SW1.2, U2.19 (~RESET), U3.7 (NRST), U4.29 (~RESET~/PC6), U5.5 (NRST), U7.10 (RESET#)
RX: J16.6, U3.16 (PA2), U5.11 (TX)
RXD: J16.3, J16.7, U7.3 (RXD)
RX_LED: D9.1 (K), U7.16 (RXLED#)
SW1: J11.1, U3.20 (PA4)
SW2: J14.1, U3.21 (PA5)
SWCLK: U3.49 (PA14), U5.2 (SWCLK)
SWDIO: U3.46 (PA13), U5.4 (SWDIO)
TX: J16.8, U3.17 (PA3), U5.12 (RX)
TXD: J16.1, J16.5, U7.2 (TXD)
TX_LED: D11.1 (K), U7.17 (TXLED#)

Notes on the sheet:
STM32F446RE
MCP2515
MCP2561
AtMega328P

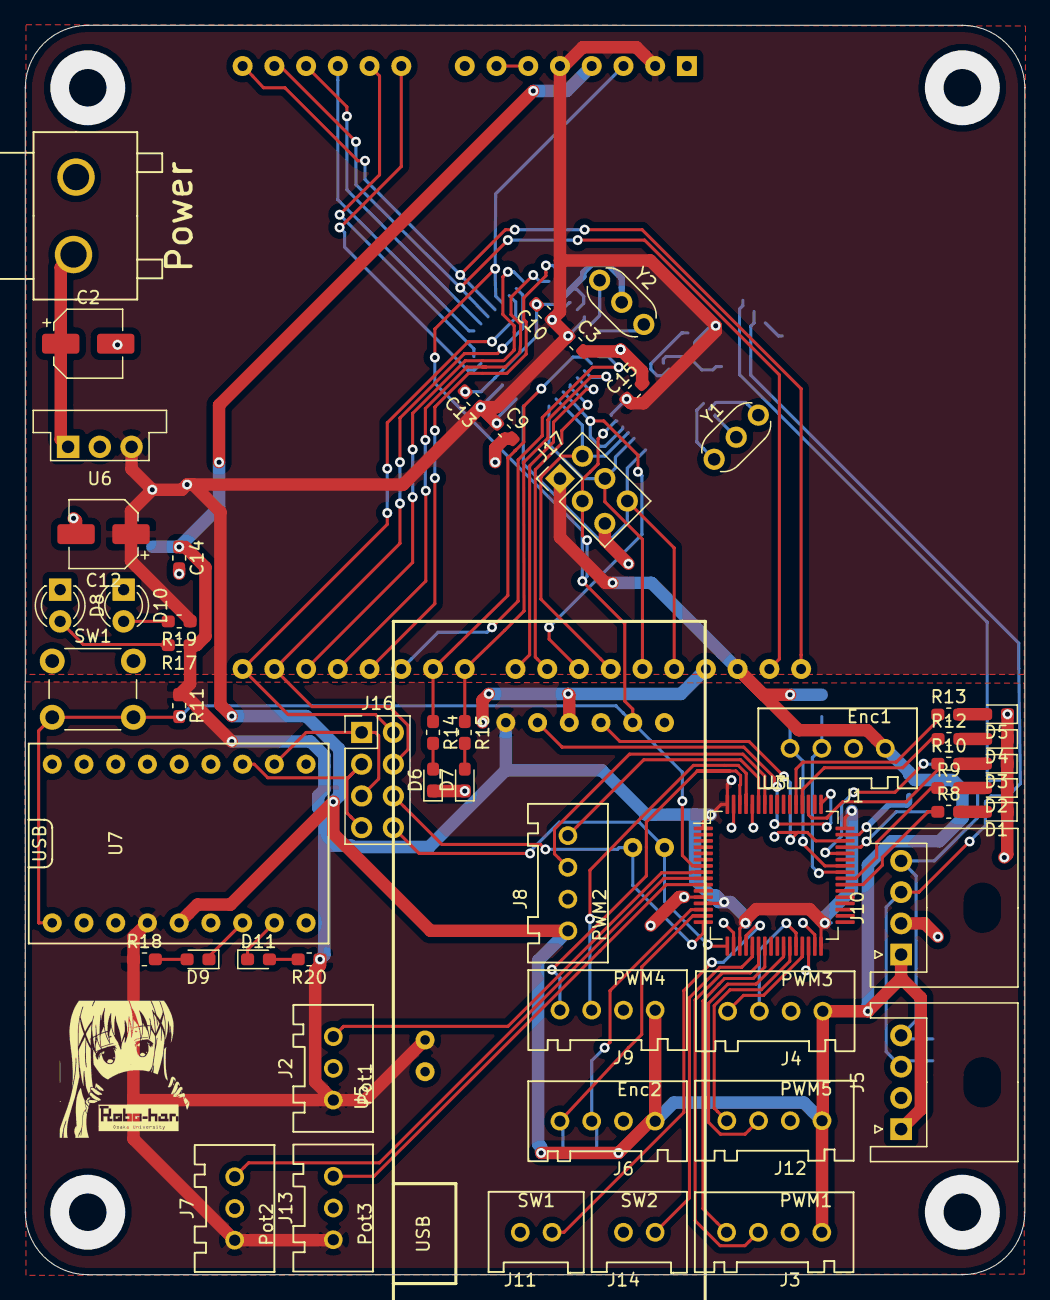
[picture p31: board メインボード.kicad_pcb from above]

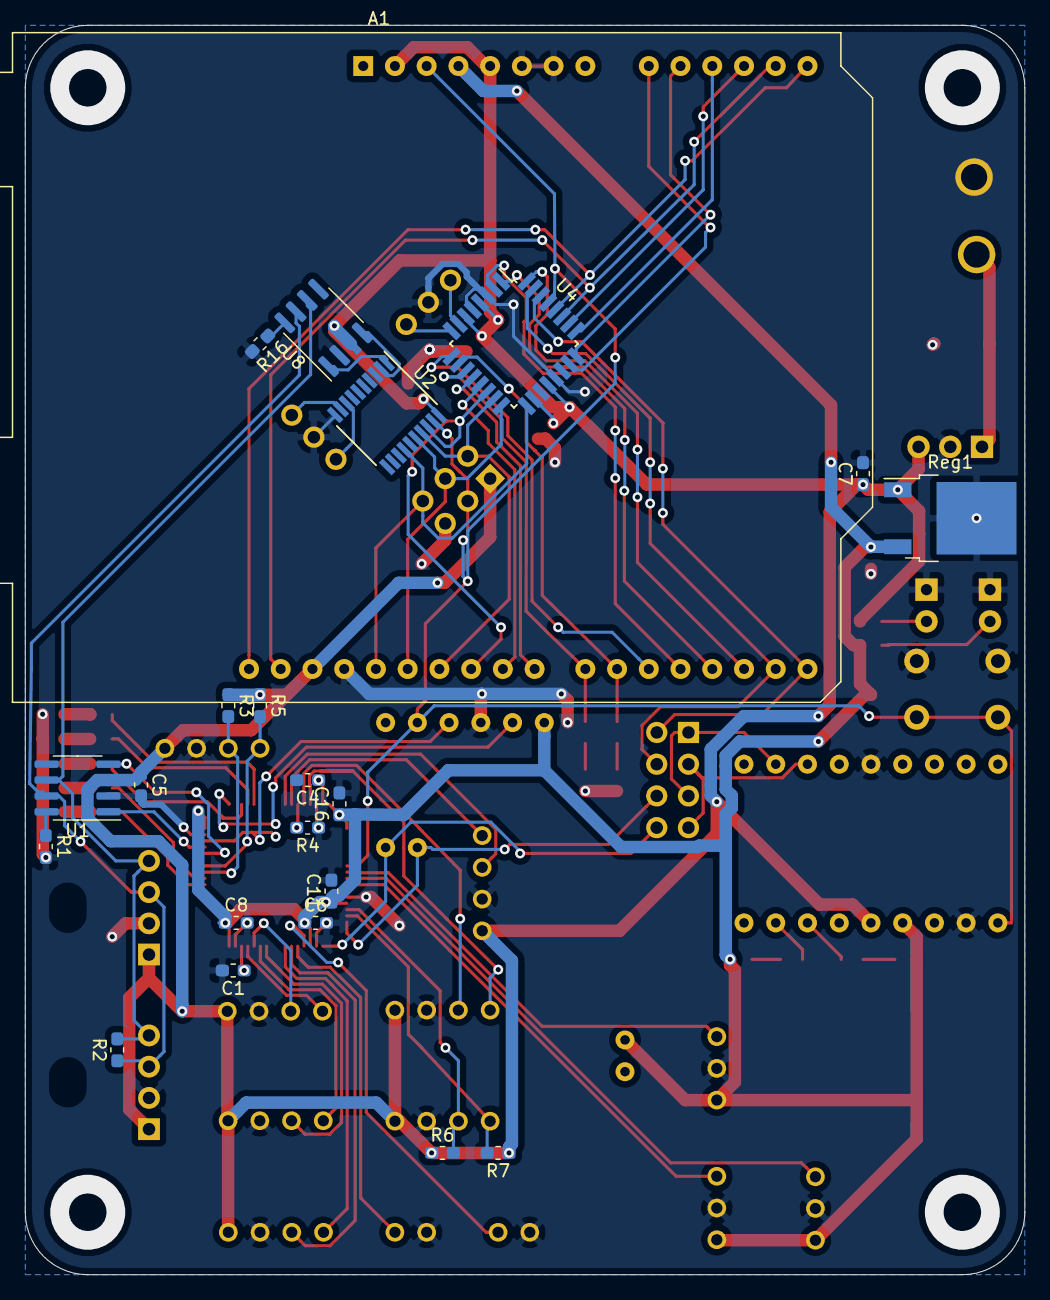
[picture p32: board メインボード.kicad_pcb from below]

Board: 2 copper layers, 80.0 x 100.0 mm, 77 parts (22 on the bottom side), 82 nets.

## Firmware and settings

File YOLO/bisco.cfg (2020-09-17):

[net]
# Testing
# batch=1
# subdivisions=1
# Training
batch=32
subdivisions=16
width=160
height=160
channels=3
momentum=0.9
decay=0.0005
angle=0
saturation = 1.5
exposure = 1.5
hue=.1

learning_rate=0.001
burn_in=1000
max_batches = 500200
policy=steps
steps=400000,450000
scales=.1,.1

[convolutional]
batch_normalize=1
filters=32
size=3
stride=1
pad=1
activation=leaky

# Downsample

[convolutional]
batch_normalize=1
filters=64
size=3
stride=2
pad=1
activation=leaky

[convolutional]
batch_normalize=1
filters=32
size=1
stride=1
pad=1
activation=leaky

[convolutional]
batch_normalize=1
filters=64
size=3
stride=1
pad=1
activation=leaky

[shortcut]
from=-3
activation=linear

# Downsample

[convolutional]
batch_normalize=1
filters=128
size=3
stride=2
pad=1
activation=leaky

[convolutional]
batch_normalize=1
filters=64
size=1
stride=1
pad=1
activation=leaky

[convolutional]
batch_normalize=1
filters=128
size=3
stride=1
pad=1
activation=leaky

[shortcut]
from=-3
activation=linear

[convolutional]
batch_normalize=1
filters=64
size=1
stride=1
pad=1
activation=leaky

[convolutional]
batch_normalize=1
filters=128
size=3
stride=1
pad=1
activation=leaky

[shortcut]
from=-3
activation=linear

# Downsample

[convolutional]
batch_normalize=1
filters=256
size=3
stride=2
pad=1
activation=leaky

[convolutional]
batch_normalize=1
filters=128
size=1
stride=1
pad=1
activation=leaky

[convolutional]
batch_normalize=1
filters=256
size=3
stride=1
pad=1
activation=leaky

[shortcut]
from=-3
activation=linear

[convolutional]
batch_normalize=1
filters=128
size=1
stride=1
pad=1
activation=leaky

[convolutional]
batch_normalize=1
filters=256
size=3
stride=1
pad=1
activation=leaky

[shortcut]
from=-3
activation=linear

[convolutional]
batch_normalize=1
filters=128
size=1
stride=1
pad=1
activation=leaky

[convolutional]
batch_normalize=1
filters=256
size=3
stride=1
pad=1
activation=leaky

[shortcut]
from=-3
activation=linear

[convolutional]
batch_normalize=1
filters=128
size=1
stride=1
pad=1
activation=leaky

[convolutional]
batch_normalize=1
filters=256
size=3
stride=1
pad=1
activation=leaky

[shortcut]
from=-3
activation=linear


[convolutional]
batch_normalize=1
filters=128
size=1
stride=1
pad=1
activation=leaky

[convolutional]
batch_normalize=1
filters=256
size=3
stride=1
pad=1
activation=leaky

[shortcut]
from=-3
activation=linear

[convolutional]
batch_normalize=1
filters=128
size=1
stride=1
pad=1
activation=leaky

[convolutional]
batch_normalize=1
filters=256
size=3
stride=1
pad=1
activation=leaky

[shortcut]
from=-3
activation=linear

[convolutional]
batch_normalize=1
filters=128
size=1
stride=1
pad=1
activation=leaky

[convolutional]
batch_normalize=1
filters=256
size=3
stride=1
pad=1
activation=leaky

[shortcut]
from=-3
activation=linear

[convolutional]
batch_normalize=1
filters=128
size=1
stride=1
pad=1
activation=leaky

[convolutional]
batch_normalize=1
filters=256
size=3
stride=1
pad=1
activation=leaky

[shortcut]
from=-3
activation=linear

# Downsample

[convolutional]
batch_normalize=1
filters=512
size=3
stride=2
pad=1
activation=leaky

[convolutional]
batch_normalize=1
filters=256
size=1
stride=1
pad=1
activation=leaky

[convolutional]
batch_normalize=1
filters=512
size=3
stride=1
pad=1
activation=leaky

[shortcut]
from=-3
activation=linear


[convolutional]
batch_normalize=1
filters=256
size=1
stride=1
pad=1
activation=leaky

[convolutional]
batch_normalize=1
filters=512
size=3
stride=1
pad=1
activation=leaky

[shortcut]
from=-3
activation=linear


[convolutional]
batch_normalize=1
filters=256
size=1
stride=1
pad=1
activation=leaky

[convolutional]
batch_normalize=1
filters=512
size=3
stride=1
pad=1
activation=leaky

[shortcut]
from=-3
activation=linear


[convolutional]
batch_normalize=1
filters=256
size=1
stride=1
pad=1
activation=leaky

[convolutional]
batch_normalize=1
filters=512
size=3
stride=1
pad=1
activation=leaky

[shortcut]
from=-3
activation=linear

[convolutional]
batch_normalize=1
filters=256
size=1
stride=1
pad=1
activation=leaky

[convolutional]
batch_normalize=1
filters=512
size=3
stride=1
pad=1
activation=leaky

[shortcut]
from=-3
activation=linear


[convolutional]
batch_normalize=1
filters=256
size=1
stride=1
pad=1
activation=leaky

[convolutional]
batch_normalize=1
filters=512
size=3
stride=1
pad=1
activation=leaky

[shortcut]
from=-3
activation=linear


[convolutional]
batch_normalize=1
filters=256
size=1
stride=1
pad=1
activation=leaky

[convolutional]
batch_normalize=1
filters=512
size=3
stride=1
pad=1
activation=leaky

[shortcut]
from=-3
activation=linear

[convolutional]
batch_normalize=1
filters=256
size=1
stride=1
pad=1
activation=leaky

[convolutional]
batch_normalize=1
filters=512
size=3
stride=1
pad=1
activation=leaky

[shortcut]
from=-3
activation=linear

# Downsample

[convolutional]
batch_normalize=1
filters=1024
size=3
stride=2
pad=1
activation=leaky

[convolutional]
batch_normalize=1
filters=512
size=1
stride=1
pad=1
activation=leaky
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

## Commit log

2020-08-31 作業に応じてMarkdown編集
2020-08-31 Add CAD & docs
    [12ｘ12_1.0012.ipt, 12ｘ12_1.ipt, 2019Nx-CLB-120U.ipt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]
2020-09-03 add YOLO setting
    [bisco.cfg]
2020-09-16 add ignore data
    [bisco.cfg]
